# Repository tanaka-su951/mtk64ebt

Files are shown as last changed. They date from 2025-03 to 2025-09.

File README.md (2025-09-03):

## 目次

- [mtk64ebt](#mtk64ebt)
    - [トラックボール＆ロータリーエンコーダー付きBluetooth接続自作キーボード](#トラックボールロータリーエンコーダー付きbluetooth接続自作キーボード)
    - [フットスイッチ](#フットスイッチ)
- [オンラインストア](#オンラインストア)
- [本体以外に必要なパーツとおすすめ商品](#本体以外に必要なパーツとおすすめ商品)
- [特徴](#特徴)
- [使用方法](#使用方法)
    - [モジュール間接続](#モジュール間接続)
    - [USB接続](#usb接続)
    - [Bluetooth接続](#bluetooth接続)
    - [ロープロファイル化](#ロープロファイル化)
    - [フットスイッチ拡張キット](#フットスイッチ拡張キット)
    - [フットスイッチ無線化モジュール](#フットスイッチ無線化モジュール)
- [ファームウェア](#ファームウェア)
    - [左右構成用ファームウェア](#左右構成用ファームウェア)
    - [左右＋フットスイッチ無線化モジュール用ファームウェア](#左右フットスイッチ無線化モジュール用ファームウェア)
    - [ファームウェア書き込み](#ファームウェア書き込み)
- [ソースコード](#ソースコード)
    - [左右構成用ファームウェアブランチ](#左右構成用ファームウェアブランチ)
    - [左右＋フットスイッチ無線化モジュール用ブランチ](#左右フットスイッチ無線化モジュール用ブランチ)
- [ZMK Studioでキーマッピング変更](#zmk-studioでキーマッピング変更)
    - [ブラウザ版 ZMK Studio](#ブラウザ版-zmk-studio)
    - [アプリ版 ZMK Studio](#アプリ版-zmk-studio)
- [KeymapEditorでキーマッピング変更](#keymapeditorでキーマッピング変更)
- [トラックボール設定](#トラックボール設定)
    - [トラックボール設定変更](#トラックボール設定変更)
    - [レイヤー設定変更](#レイヤー設定変更)
    - [トラックボール設定値調整](#トラックボール設定値調整)
- [ケースデータ](#ケースデータ)

# mtk64ebt
<br>

### トラックボール＆ロータリーエンコーダー付きBluetooth接続自作キーボード

mtk64ebtは、親指操作トラックボールとロータリーエンコーダーを搭載した完全ワイヤレス接続分割式キーボードです。

トラックボールとエンコーダーの組み合わせにより、直感的で効率的な操作を実現します。

ワイヤレス接続によりケーブルの煩わしさから解放され、どこへでも快適に持ち運べます。

はんだ付けとケースの組み立てが完了している半完成キットです。キースイッチとキーキャップ、トラックボールを取り付けるだけで、すぐに使用を開始することができます。

#### Rev.3の特徴
基板設計とケース設計を更新してRev.3になりました。

##### バッテリーケースのスリム化
部品配置の見直しにより、バッテリーサイズはそのままでバッテリーケースをスリム化しました。(バッテリーケース部厚み 22mm → 18.5mm)
ケース形状も変更してすっきりした見た目になっています。

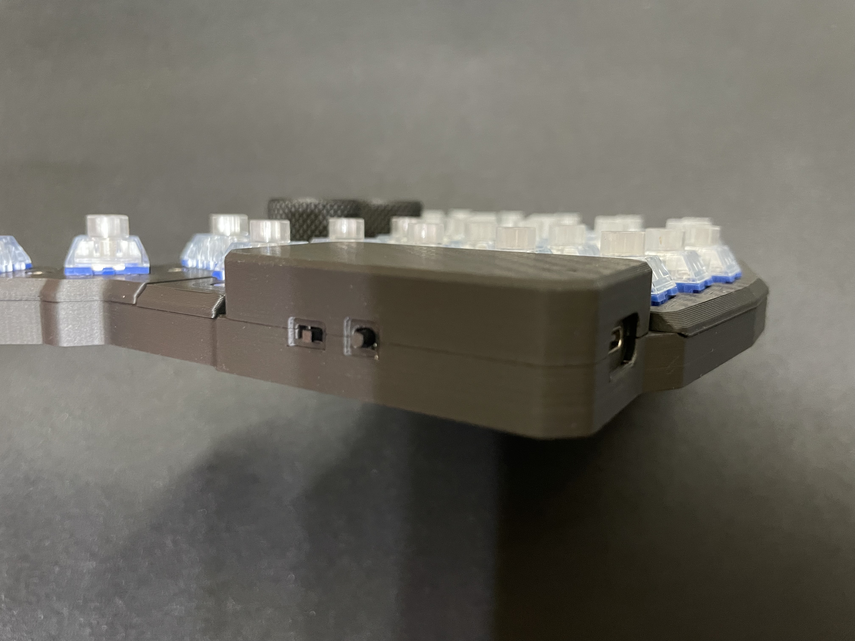
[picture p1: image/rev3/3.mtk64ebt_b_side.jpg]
<br>

##### LEDレンズ
インジケーターLEDにレンズを追加したことにより、視認性が向上しました。
バッテリー残量、接続状態、レイヤー切り替えが確認しやすくなりました。

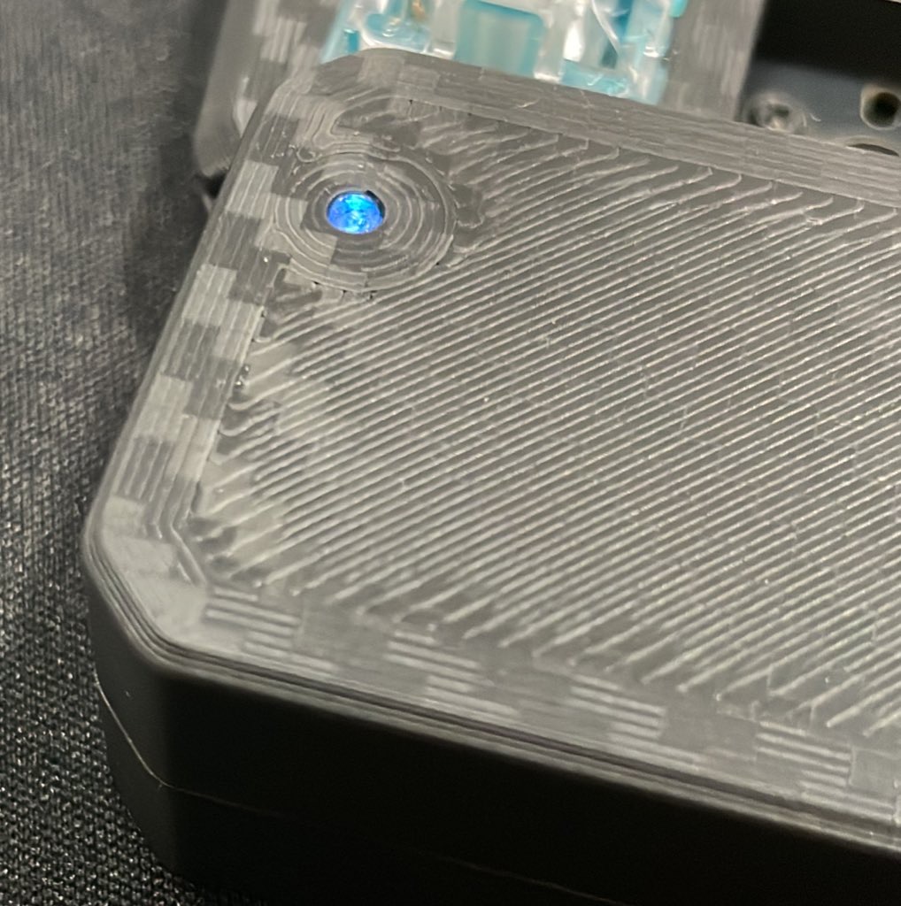
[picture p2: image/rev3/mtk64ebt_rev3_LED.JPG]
<br>

##### フットスイッチ完全無線化
ケーススリム化と生産性向上のため、左右キーボードのフットスイッチ有線接続ジャックを廃止。付属の無線フットスイッチキットによる無線接続に一本化しました。

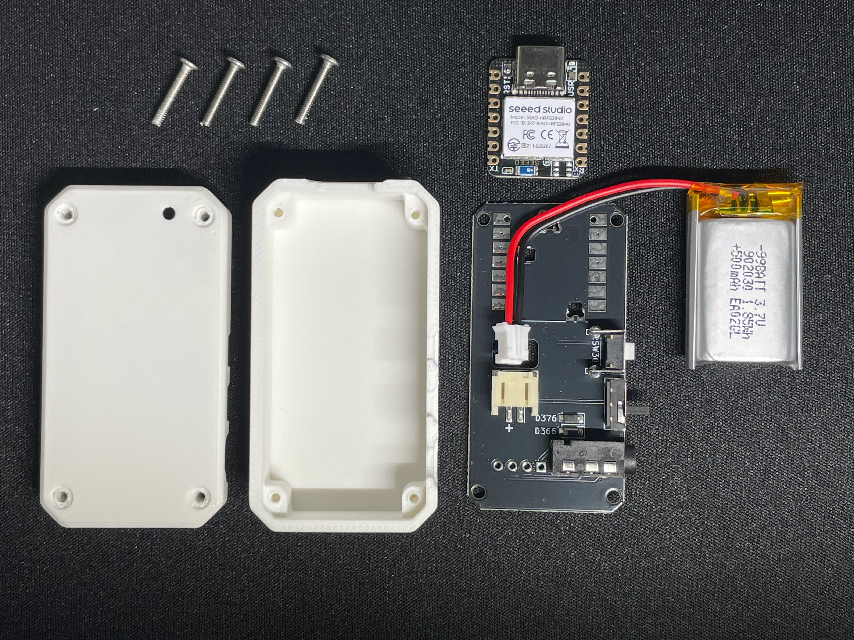
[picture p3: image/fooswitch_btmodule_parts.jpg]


##### ベアリング仕様トラックボールケース対応
トラックボール支持球をベアリングに置き換えるケースデータを公開しています。
ご自身でプリントしてベアリング仕様に変更可能です。

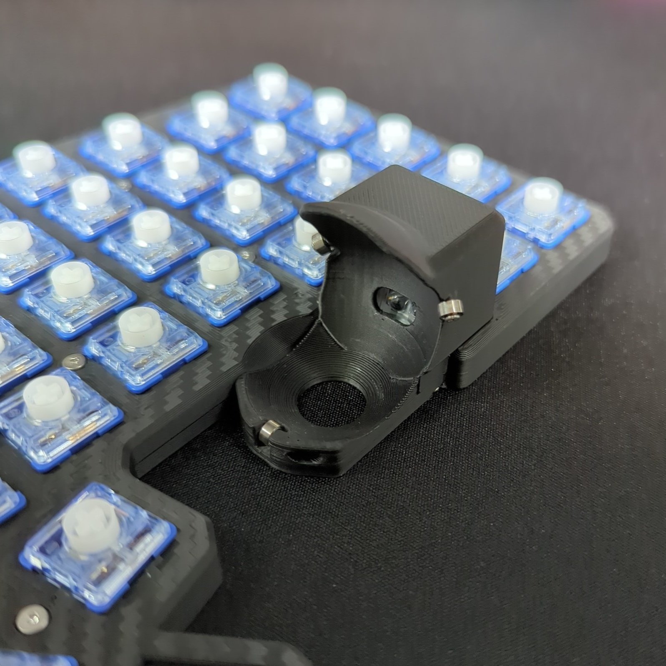
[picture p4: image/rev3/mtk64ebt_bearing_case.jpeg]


ケースの他に、ベアリング(内径 1.5mm 外径 4mm 幅 2mmのシールドタイプ)とM1.4のネジが必要です。
* ベアリング : [ミネベアミスミ DDL-415ZZ](https://amzn.asia/d/fXq8wOI)
* ネジ : [M1.4-0.3 6mm](https://amzn.asia/d/c3SDJWJ)

###### ベアリング仕様トラックボールケースデータ
[mtk64ebt_rev3_ballBearingCase_RH.3mf](casedata/rev3/mtk64ebt_rev3_ballBearingCase_RH.3mf)<br>[mtk64ebt_rev3_bodyBallBeringBottmn_RH.3mf](casedata/rev3/mtk64ebt_rev3_bodyBallBeringBottmn_RH.3mf)

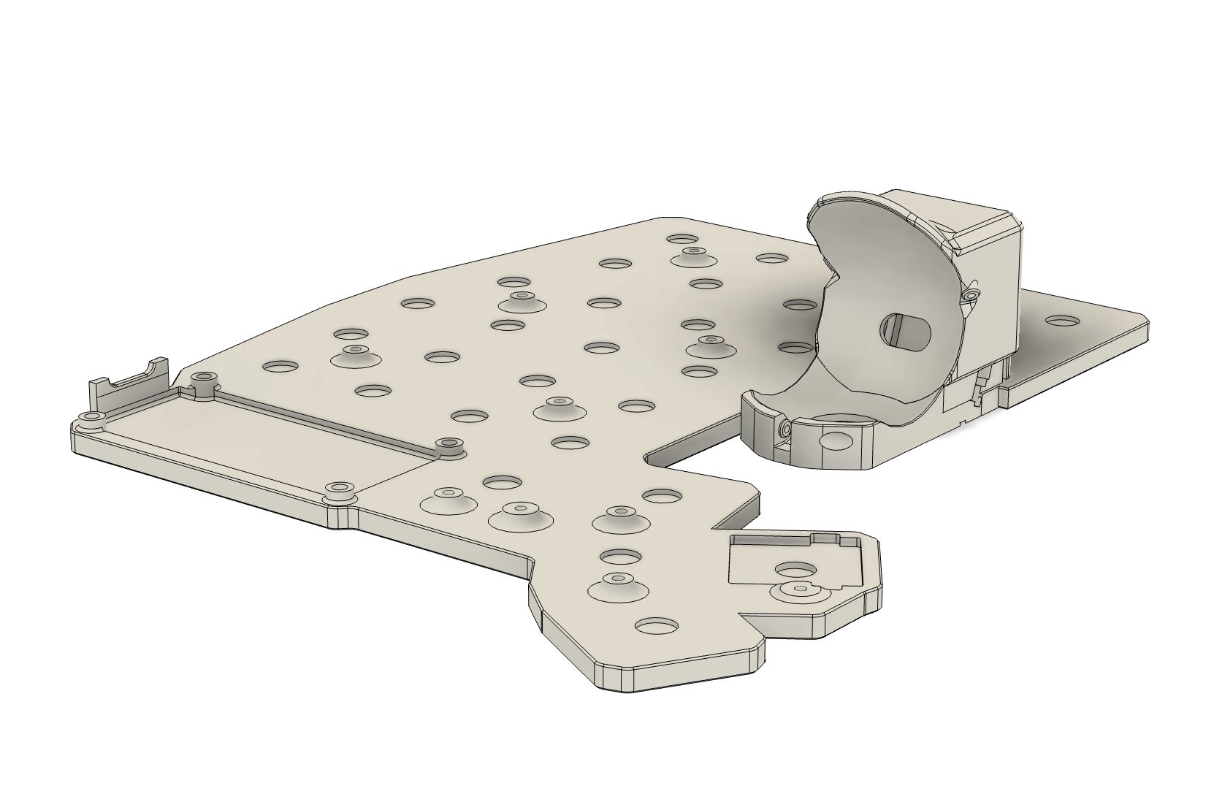
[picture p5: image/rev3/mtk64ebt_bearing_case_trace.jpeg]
<br>

### フットスイッチ
[市販のUSBフットスイッチ](https://amzn.asia/d/h7wMR24)の基板を付属のフットスイッチ拡張基盤に差し替えてmtk64の拡張無線フットスイッチとして使用可能です。

フットスイッチも含めて完全ワイヤレス化可能となり、デスク環境からケーブルの煩わしさを一掃できます。

フットスイッチ拡張基板はご自身ではんだ付けと組み立てが必要なキットです。

<br>

> [!CAUTION]
> バッテリー駆動用に[リチウムポリマーバッテリー](https://amzn.asia/d/1ivvf2l)を使用します。
> バッテリーの取り扱いを誤った場合や、製造上の不具合により、破裂や発火の恐れがあります。
> 組み立ての際に動作確認は行っていますが、絶対に安全であることを保証するものではありません。
> バッテリーは使用者の責任において使用してください。
> バッテリー、本体基板、その他構成部品を含め、本製品による事故および不利益損害についての一切の責任は使用者にあり、当方が責任を持つものではありません。

* バッテリー駆動時および、充電時は本体側面のバッテリー駆動用スイッチをONにしてください。
* バッテリー不使用時はバッテリー駆動用スイッチをOFFにしてください。
* 充電中は、発火・破裂しても被害のない場所を選定し、周囲に延焼するものを置かないようにして下さい。また充電中はその場を離れ ることなく常に Li-Po の充電状態を監視して下さい。
* バッテリーの取り扱いや製造上の不具合について懸念がある場合や、ご自身の責任で使用できない場合、キーボードからバッテリーを取り外してご使用ください。
USB端子からの給電のみでキーボードを使用できます。

## オンラインストア
https://mentako-ya.myshopify.com

## 本体以外に必要なパーツとおすすめ商品

キーキャップMX互換: [CORSAIR PBT DOUBLE-SHOT 交換用カラーキーキャップセット - 日本語108キー, Arctic White - CH-9911040-JP](https://amzn.asia/d/1FShFiO)

キーキャップChocV2: [XVX ロープロファイル PBT キーキャップ](https://amzn.asia/d/7V1A6T4)

キーキャップChocV1: [Chocfox CFX keycap](https://chosfox.com/products/chocfox-cfx-choc-keycaps?bg_ref=3KtshOemT6)

トラックボール: [ぺリックス PERIPRO-303WH 34mm](https://amzn.asia/d/1paUF5C)

USB Type-cケーブル: https://amzn.asia/d/h8pfZIJ

クッションゴム: [ダイソー クッションゴム透明](https://jp.daisonet.com/products/4903409153222)

T5ドライバー(メンテナンス用): [アネックス(ANEX) ドライバー ヘクスローブ T4x50](https://amzn.asia/d/8RFoACS)

## 特徴

標準的な６０％キーボード相当のキースイッチ＋フットスイッチ拡張で、一般的なキーボードからの移行コストを抑え、フルキーボード以上の操作性を実現します。

[ZMK Studio](#zmk-studioでキーマッピング変更)を使用して、キーマッピングを簡単に変更することができます。

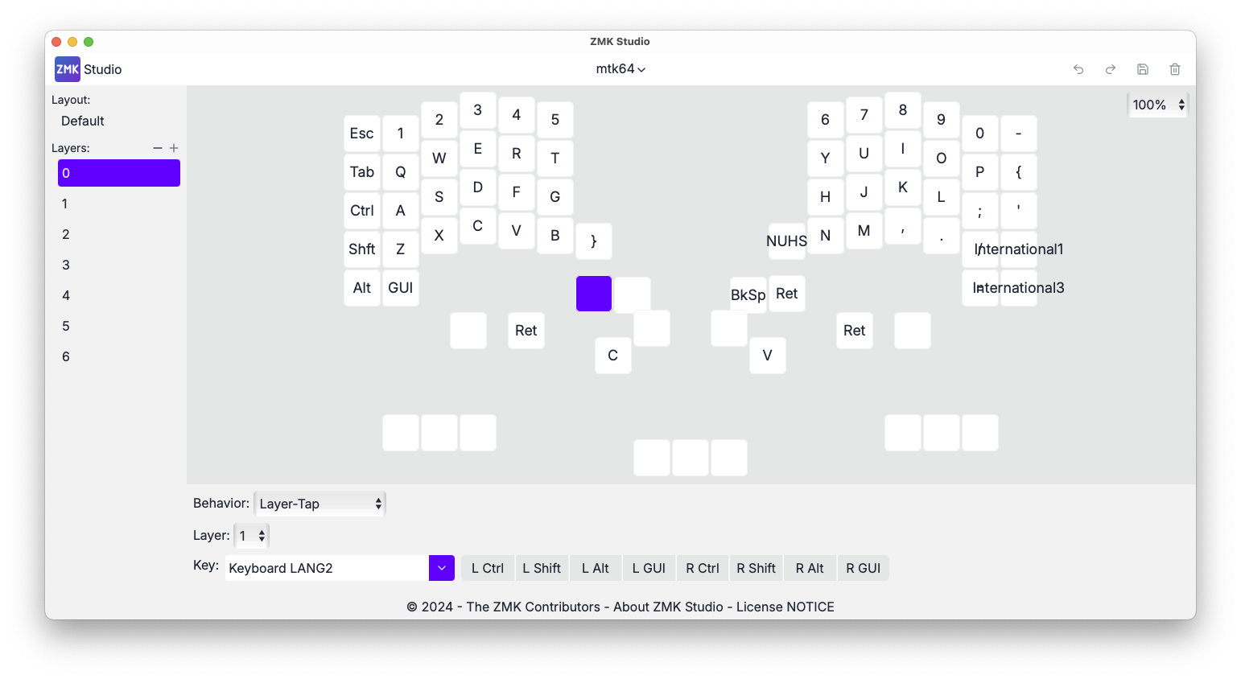
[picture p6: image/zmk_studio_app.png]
<br>

親指操作トラックボールを搭載しています。
キー操作時のトラックボールへの干渉を避けるため、トラックボールの取り付け位置は極力低くオフセットされています。
トラックボールケース底面もフラット形状にして、全体の高さを抑えました。

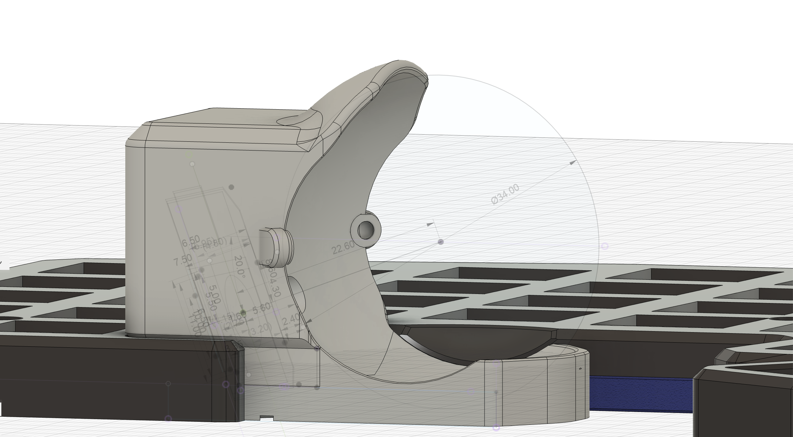
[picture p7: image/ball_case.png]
<br>

PMW3610トラックボールセンサーは、センサー基板を小型化して取り付け角度を20度に設定しました。
テンティングなしでも快適にトラックボールを操作することができます。

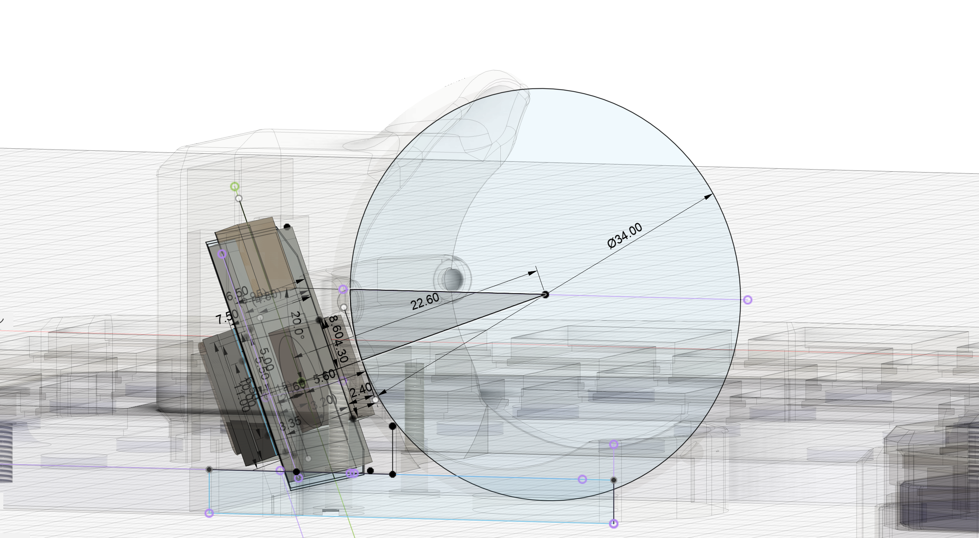
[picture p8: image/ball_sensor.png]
<br>

Alps alpine製の低背エンコーダーが２つ搭載されています。30クリックの回転操作とプッシュスイッチが付いており、直感的な操作が可能です。

<br>

Choc V1、[V2（固定ピンなしモデル）](https://ja.aliexpress.com/item/1005007361067887.html)、およびMX互換キースイッチを全てのキーに取り付けることが可能です。

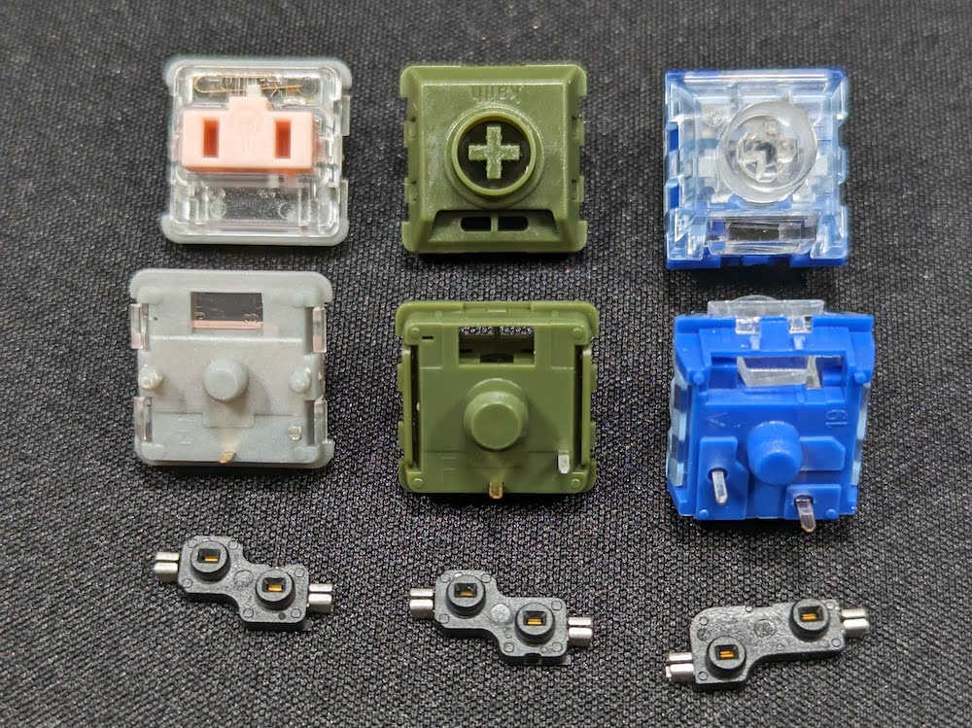
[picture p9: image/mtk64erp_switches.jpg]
<br>
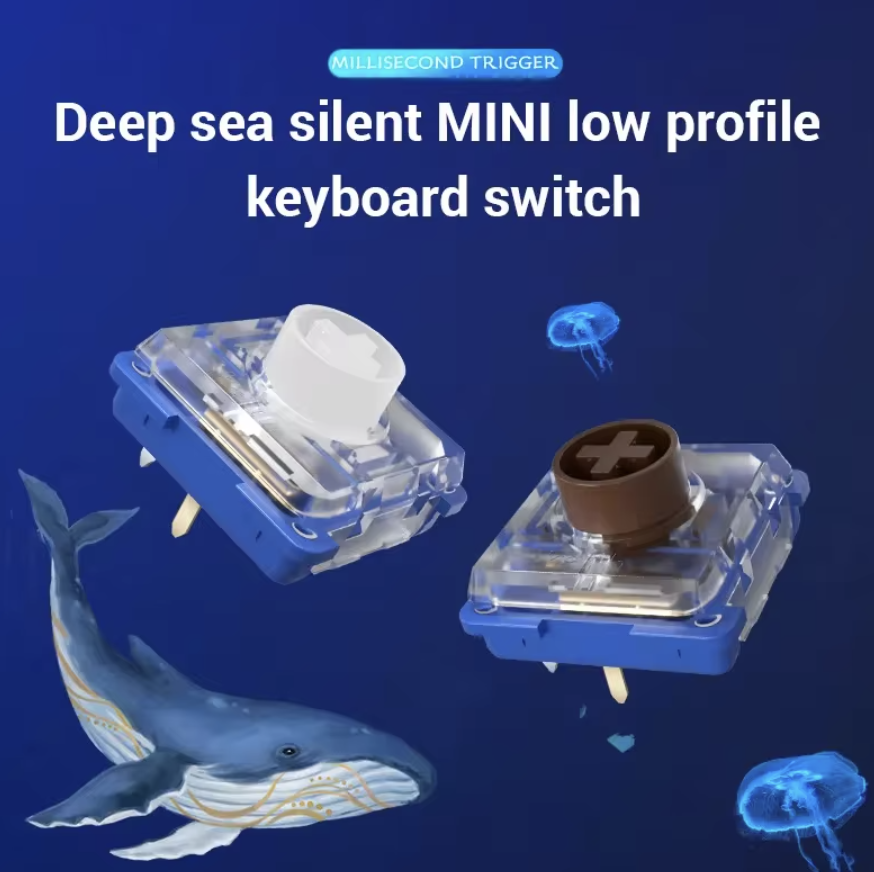
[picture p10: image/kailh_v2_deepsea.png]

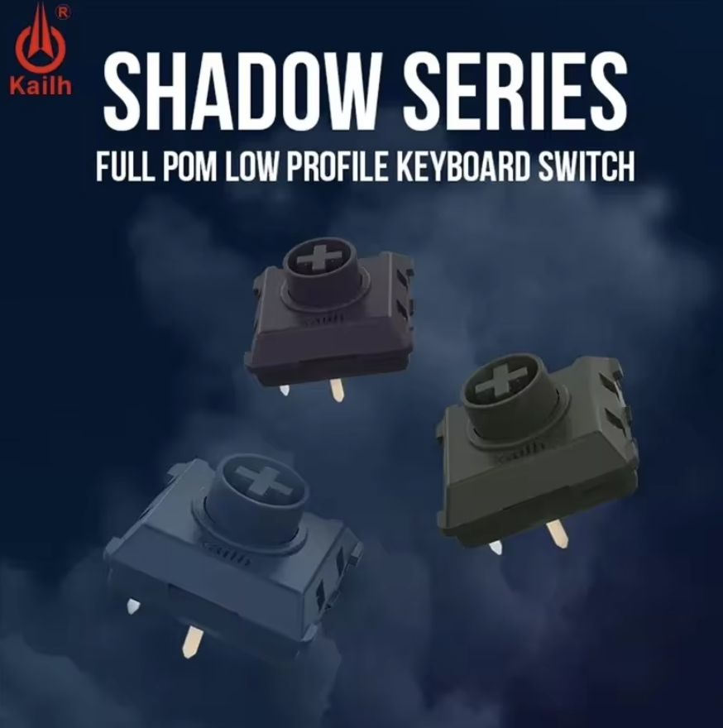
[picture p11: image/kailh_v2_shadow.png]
<br>

親指部分のみをロープロファイル化することも可能です。

追加の親指キースイッチは、操作性を向上させるため、さらに一段低くオフセットされています。

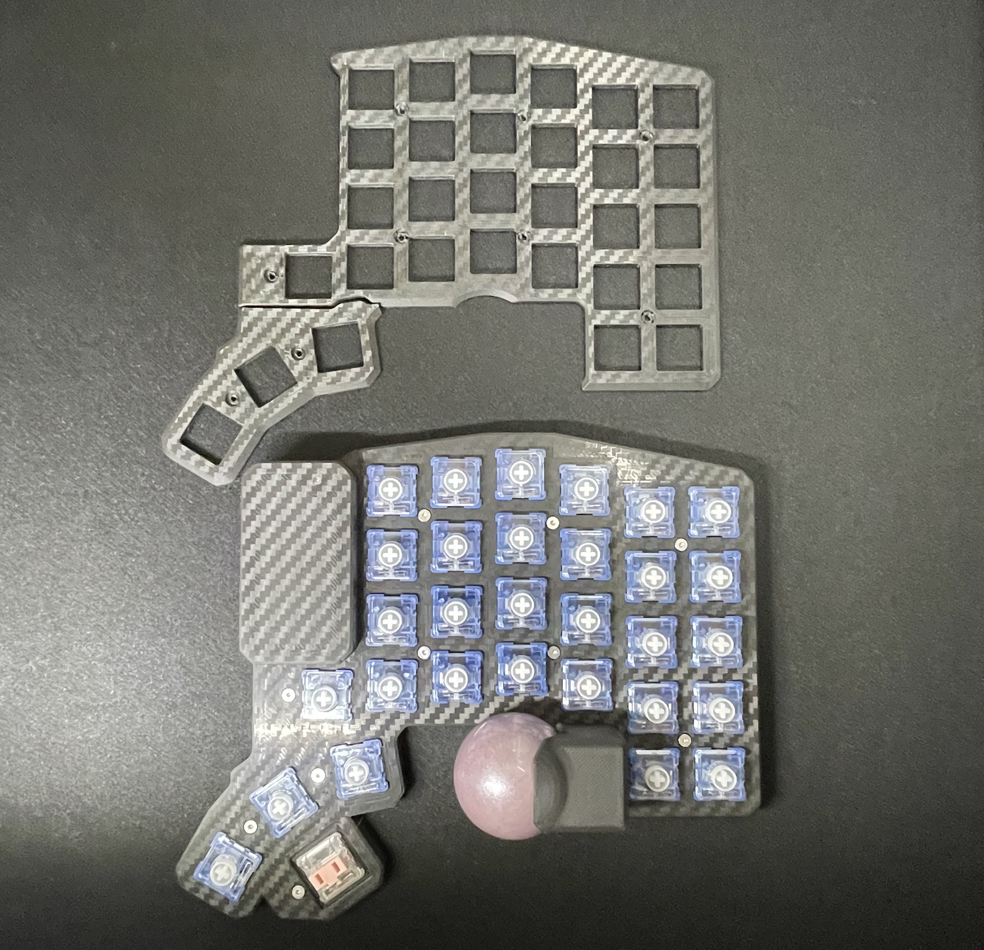
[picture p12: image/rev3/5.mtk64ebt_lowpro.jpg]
<br>

MCUに[Seeed Studio XIAO nRF52840](https://jp.seeedstudio.com/Seeed-XIAO-BLE-nRF52840-p-5201.html)を使用しており、無線接続の自作キーボードで課題となる技適対応もクリアしています。

技術基準適合証明番号：[211-220207](https://www.tele.soumu.go.jp/giteki/SearchServlet?pageID=jk01&NUM_TYPE=1&NUM=211-220207)

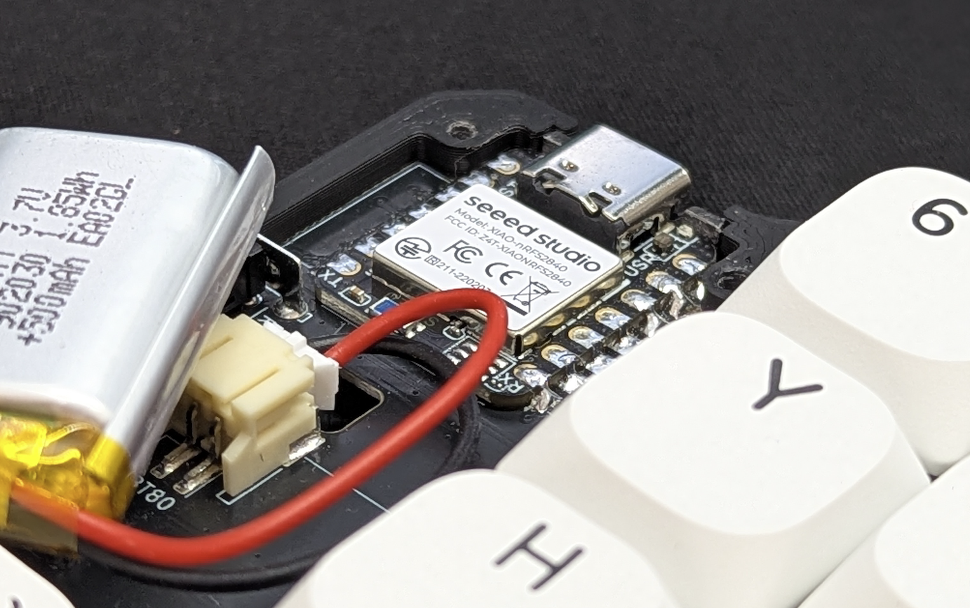
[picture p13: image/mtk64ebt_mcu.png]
<br>

無線接続では、有線接続に比べてポーリングレートが低くなりますが、通常利用には問題なく使用することが可能です。（約70hz）

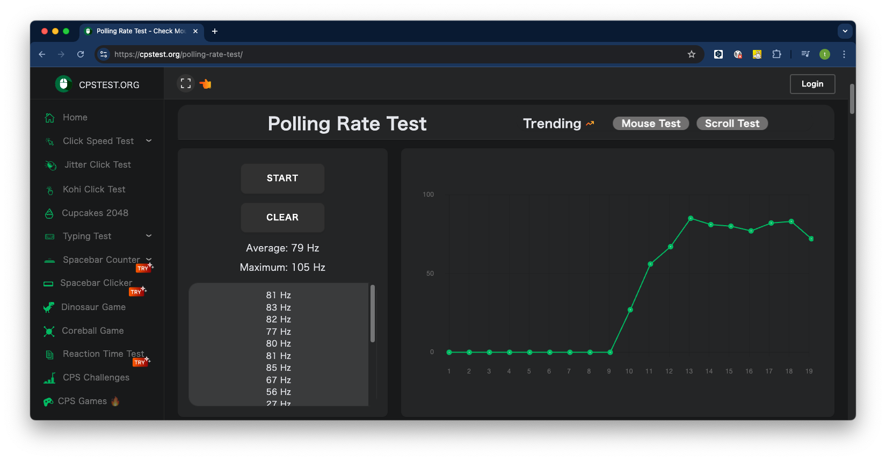
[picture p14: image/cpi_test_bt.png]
<br>

USB接続時には、ポーリングレートが向上し、よりスムーズに動作します。（約220hz）精密なトラックボール操作が求められる場面で効果的です。

有線接続時も右手のみUSB接続となり、左手側は無線接続となるので、USBケーブル１本だけで接続となります。左右間接続用のTRRSケーブルは使用しません。

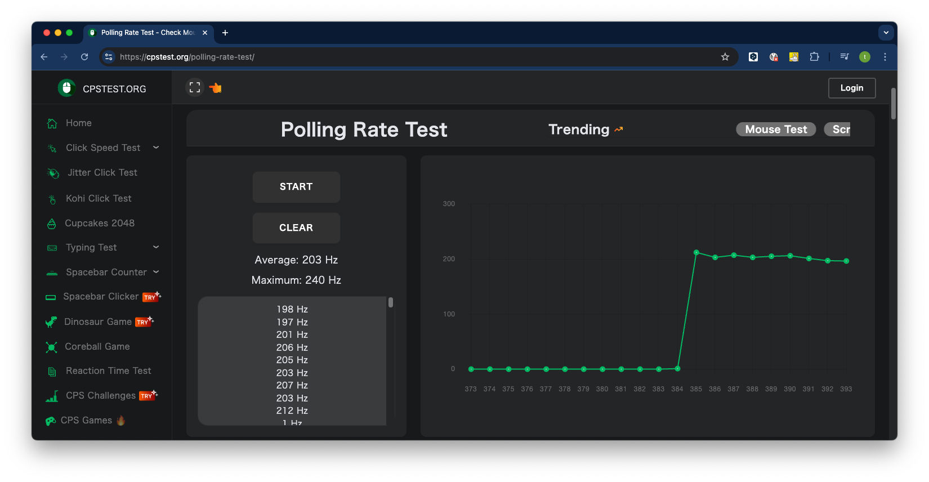
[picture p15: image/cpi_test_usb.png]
<br>

[Seeed Studio XIAO BLE](https://jp.seeedstudio.com/Seeed-XIAO-BLE-nRF52840-p-5201.html) もしくは [nrf54820搭載モジュール](https://www.switch-science.com/products/5531) をドングルとして使用することで、左右のキーボードは無線接続のまま、有線接続相当のポーリングレート（約110~220hz）で動作します。

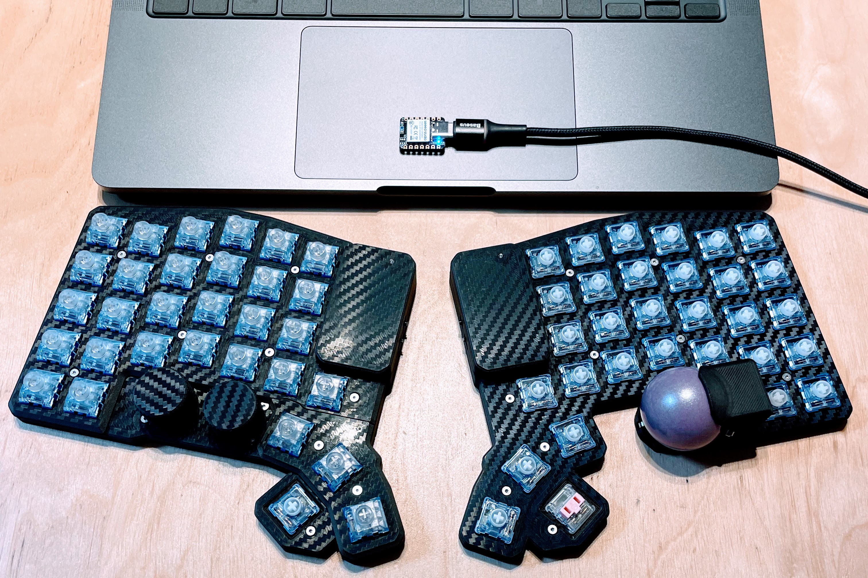
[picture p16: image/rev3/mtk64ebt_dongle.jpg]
<br>

[mtk64ebt ドングル使用時ポーリングレート計測ムービー](https://www.youtube.com/embed/7DrP1KA7Fw4?list=PL_GJMtxZ-TgovRiROU55VTm1dNuUvYyni)

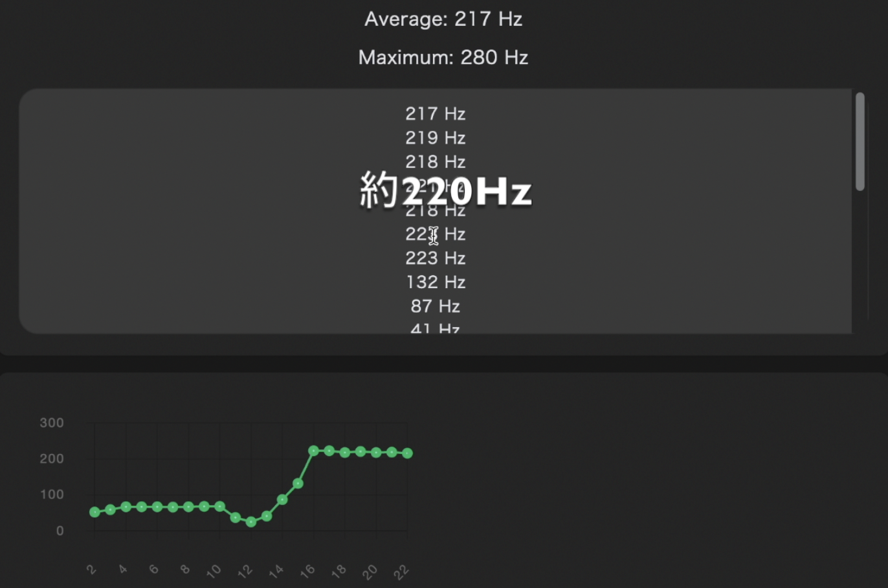
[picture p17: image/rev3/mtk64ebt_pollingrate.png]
<br>

右手側のLEDで現在のレイヤーが確認できるようになりました。
```
レイヤー０ ⚫️Black（無点灯）
レイヤー１ 🟣Magenta トラックボール精密モード
レイヤー２ 🔵Cyan    トラックボールモード
レイヤー３ 🟡Yellow  スクロールモード
レイヤー４ 🟢Green
レイヤー５ 🔵Blue
レイヤー６ ⚪️White   自動マウスレイヤー
```

## フットスイッチ拡張基板

[市販のUSBフットスイッチ](https://amzn.asia/d/h7wMR24)の基板を付属のフットスイッチ拡張基盤に差し替えてmtk64のフットスイッチとして使用可能です。

フットスイッチはmtk64の一部として機能するので、レイヤー切り替えやカスタムキーなどキーボード固有の操作が可能です。


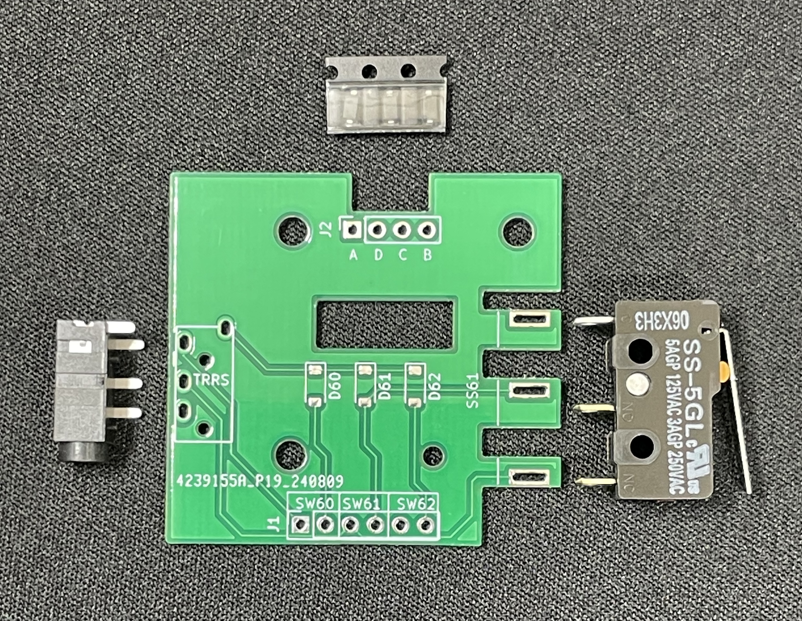
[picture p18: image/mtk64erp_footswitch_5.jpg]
<br>

フットスイッチ無線化モジュールに接続して、無線フットスイッチ構成にアップグレード可能です。

<br>  

# 使用方法

## モジュール間接続

mtk64bleは、右手モジュールがセントラルモジュールとして動作します。左手モジュールとフットスイッチは右手モジュールに自動的にペアリングされます。

各モジュールのLEDの色と接続状態については、[こちら](https://github.com/mentako-ya/zmk-rgbled-widget/blob/main/README.md)を参照してください。LEDの色によって接続状態が視覚的に確認できるため、接続状況を簡単に把握することができます。

各モジュール間の接続ができない場合は、ファームウェア書き込み手順に従って、各モジュールの接続をリセットしてください。接続の問題を解決して再度正常に動作させることができます。

## USB接続

右手モジュール（セントラルモジュール）は、PCとUSBで有線接続可能です。USB接続時、セントラルモジュールはPCとの通信を行いながら、充電も行います。

左手モジュールやフットスイッチ無線化モジュール（ペリフェラルモジュール）は、USB接続時に充電のみを行います。これらのモジュールは、操作に必要な通信をすべて無線接続でセントラルモジュールと行います。

> [!CAUTION]
> Rev.2以前の右手モジュールと左手モジュールにある3.5mmジャックはフットスイッチ拡張キットを有線接続するための端子です。
> 左右間の有線接続用ではありません。
> 故障の原因となるので、左右のキーボードをTRSケーブルで接続しないでください。

## Bluetooth接続

レイヤー1の「ESC」「1」〜「5」キーを使用して、最大６か所のBluetooth接続先を切り替えることができます。。



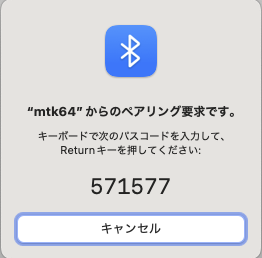
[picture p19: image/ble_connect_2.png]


接続時には、表示されたPIN番号を入力し、Enterキーを押下してください。接続後にキーボードが動作しない場合は、リセットボタンを押下して再接続を試みてください。これにより、接続の問題を解決し、正常に動作させることができます。

## ロープロファイル化

Choc V1、V2を使用する場合、トッププレート固定用ネジ(T5 8mm)を外してトッププレートを取り除き、付属の6mmねじに付け替えます。ネジの交換にはT5ドライバーを使用します。

## フットスイッチ拡張キット

フットスイッチ拡張キットはご自身で市販のフットスイッチにキットの基盤を組み込み、はんだ付けをするキットです。

フットスイッチの作成方法は[こちらのビルドムービー](https://youtu.be/NavGAliALVc?si=JpO-xi0RZznjVi4-)をご覧ください。

フットスイッチの接続は3.5mm４極のTRRS端子を使用しますが、有線でフットスイッチを接続する場合（3ccccqaac0cm以上のケーブル長が必要な場合）、市販のTRRSケーブルは線が細すぎるので使用できません

TRRS端子とAWG28~26以上（番号が小さい方が太いです）のケーブルを組み合わせて自作します

[遊舎工房自作ケーブルキット](https://shop.yushakobo.jp/products/self-made-cable?_pos=1&_sid=79305908f&_ss=r&variant=39623339737249)

[AWG26 4Cシールドケーブル](https://shop.oyaide.com/products/mogami_2893.html)

配線の色は使用するケーブルのメーカーによって異なります。
４極プラグの端子側とフットスイッチ拡張キット側の結線は下図を参照してください。

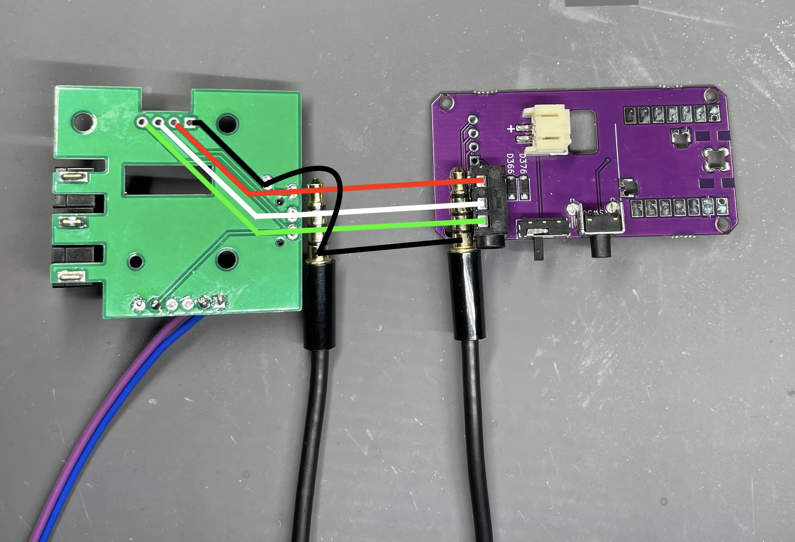
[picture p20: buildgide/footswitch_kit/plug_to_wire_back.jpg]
<br>
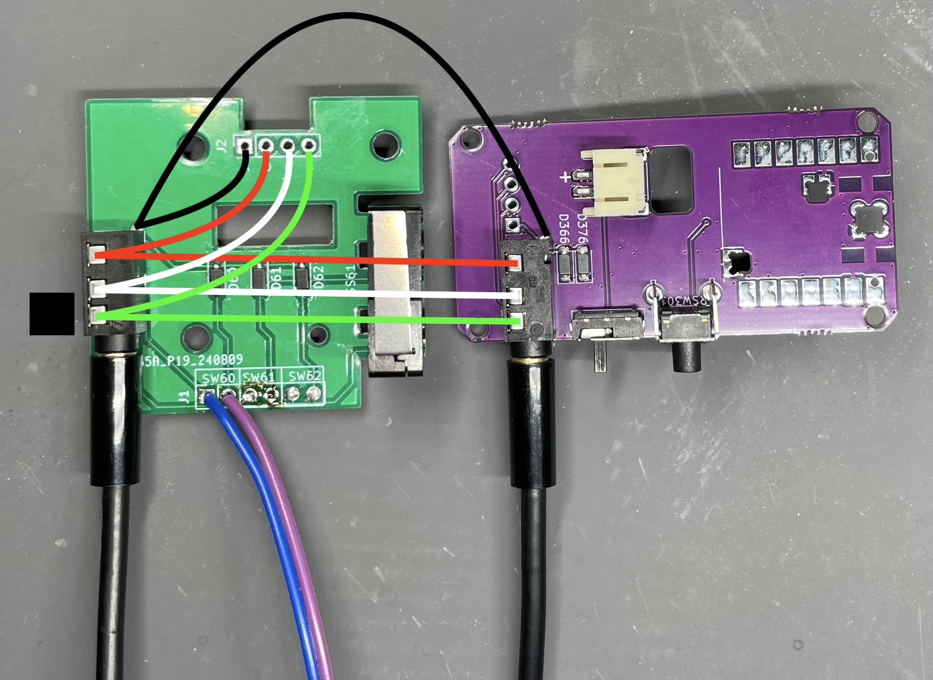
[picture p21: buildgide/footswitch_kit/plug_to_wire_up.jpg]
<br>
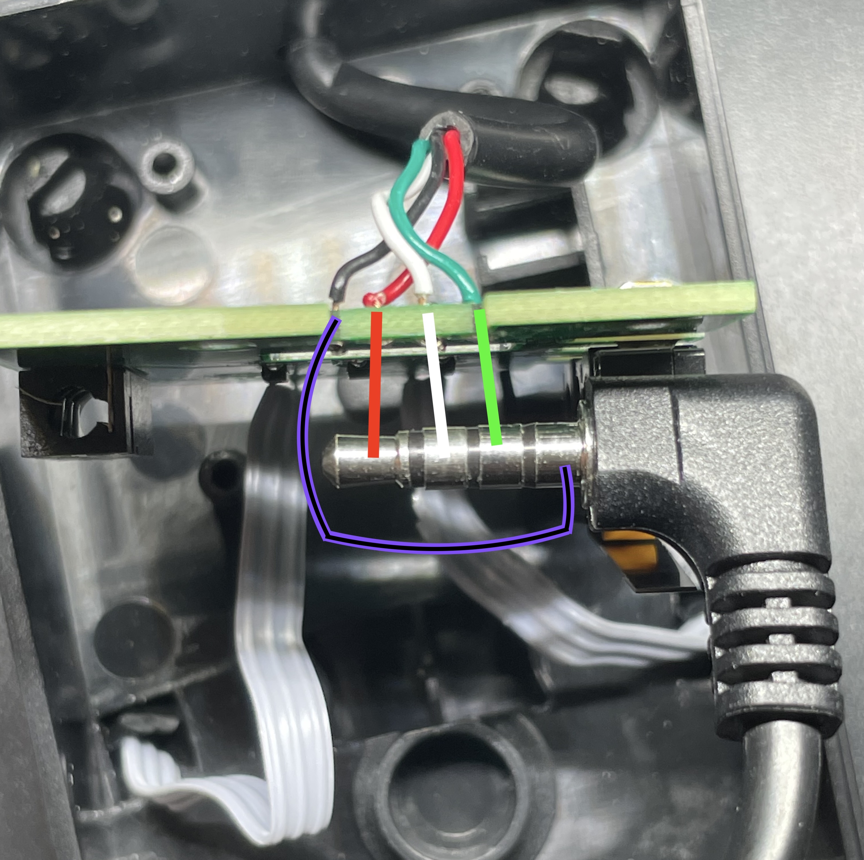
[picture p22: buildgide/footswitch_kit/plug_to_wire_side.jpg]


## フットスイッチ無線化モジュール

フットスイッチ無線化モジュールを使用する場合、[Seeed Studio XIAO nRF52840](https://jp.seeedstudio.com/Seeed-XIAO-BLE-nRF52840-p-5201.html)、[リチウムポリマーバッテリー 902030 PH2.0プラグ付き](https://ja.aliexpress.com/item/1005006838195720.html)、[ケース（ご自身で３Dプリント）](casedata/mtk64ebt_footmodule_case_LH.3mf) が別途必要です。

フットスイッチ拡張キットをフットスイッチ無線化モジュールに接続して、mtk64ebtに無線接続します。

フットスイッチキットとフットスイッチ無線化モジュールを接続する場合、フットスイッチ側の線を極力短くするのがオススメです。

写真は[こちらの４極3.5mm端子付きケーブル](https://www.digikey.jp/ja/products/detail/assmann-wsw-components/A-AV-02-45-28-183-S2/16906692)を15cmにカットして使用しています。


 

## ファームウェア

### 左右構成用ファームウェア
[mtk64ebt_Right_Left.zip](firmware/mtk64ebt_Right_Left.zip)

> [!IMPORTANT]
> フットスイッチ無線化モジュールを使用しない場合、こちらのファームウェアを使用してください。
> フットスイッチ無線化モジュールとの通信待ちで動作が遅くなる場合があります。

### 左右＋フットスイッチ無線化モジュール用ファームウェア
[mtk64ebt_Right_Left_Foot.zip](firmware/mtk64ebt_Right_Left_Foot.zip)

### 左右＋ドングルモジュール用ファームウェア
[mtk64ebt_Right_Left_Dongle.zip](firmware/mtk64ebt_Right_Left_Dongle.zip)

[Seeed Studio XIAO BLE](https://jp.seeedstudio.com/Seeed-XIAO-BLE-nRF52840-p-5201.html) もしくは [nrf54820搭載モジュール](https://www.switch-science.com/products/5531) をドングルとして使用するファームウェアです

### ファームウェア書き込み

1. 右手キーボード、左手手キーボード、フットスイッチ拡張モジュールのバッテリー駆動スイッチをOFFにする

> [!IMPORTANT]
> バッテリーから給電された状態ではファームウェア書き込み後のリセットが正しく行われません

1. 右手キーボードをPCにUSB接続してリセットボタンを短く2回押下

1. 認識された”XIAO-SENSE"に settings_reset-seeeduino_xiao_ble-zmk.uf2 をドロップ

1. 再度リセットボタンを短く2回押下

1. 認識された”XIAO-SENSE"に mtk64_R rgbled_adapter-seeeduino_xiao_ble-zmk.uf2 をドロップ

1. 左手キーボードをPCにUSB接続してリセットボタンを短く2回押下

1. 認識された”XIAO-SENSE"にsettings_reset-seeeduino_xiao_ble-zmk.uf2をドロップ

1. 再度リセットボタンを短く2回押下

1. 認識された”XIAO-SENSE"に mtk64_L rgbled_adapter-seeeduino_xiao_ble-zmk.uf2 をドロップ

1. フットスイッチ無線化モジュールをPCにUSB接続してリセットボタンを短く2回押下

1. 認識された”XIAO-SENSE"にsettings_reset-seeeduino_xiao_ble-zmk.uf2をドロップ

1. 再度リセットボタンを短く2回押下

1. 認識された”XIAO-SENSE"に mtk64_FOOT rgbled_adapter-seeeduino_xiao_ble-zmk.uf2 をドロップ

1. 右手キーボードをPCにUSB接続、左手キーボードとフットスイッチ拡張モジュールはバッテリー駆動スイッチをONにして給電する

1. 各モジュールのリセットスイッチを１回押下、各モジュール間の接続状態をUSB端子横のLEDで確認

- 右手のLEDはPCとのBluetooth接続状態を表す。
接続中🔵、オープン (アドバタイズ)🟡、切断中🔴 が点滅

- 左手とフットスイッチ無線化モジュールのLEDは、右手（セントラル）とのペアリング状態を表す。
接続の場合は🔵、切断の場合は🔴が点滅

LEDの色と接続状態についての詳細は[こちら](https://github.com/mentako-ya/zmk-rgbled-widget/blob/main/README.md)

## ソースコード

https://github.com/mentako-ya/zmk-config-mtk64

#### 左右構成用ファームウェアブランチ

https://github.com/mentako-ya/zmk-config-mtk64/tree/nofoot

#### 左右＋フットスイッチ無線化モジュール用ブランチ

https://github.com/mentako-ya/zmk-config-mtk64/tree/master

#### 左右＋ドングルモジュール用ブランチ

https://github.com/mentako-ya/zmk-config-mtk64/tree/pmw3610-bj-dongle

## ZMK Studioでキーマッピング変更

ZMK Studioを使用することで、ファームウェア書き換えなしでキーマッピングを簡単に変更することができます。

<br>

### ブラウザ版 ZMK Studio
ブラウザ版のZMK Studioを使用する場合、右手側のモジュールをUSB接続し、[こちら](https://zmk.studio/)にアクセスしてください。

### アプリ版 ZMK Studio
アプリ版のZMK Studioは、[こちら](https://zmk.studio/download)からダウンロードできます。アプリ版では、無線接続のままキーマップの変更が可能です。ケーブルを接続する手間を省き、より柔軟にキーマッピングを調整することができます。

## KeymapEditorでキーマッピング変更

キースイッチのマッピングだけでなく、エンコーダーのキーマッピング、マクロやコンボの追加、編集をしたい場合、[キーマップエディター](https://nickcoutsos.github.io/keymap-editor/)を使用して変更可能です。

キーマップエディターでマッピングを変更するためには、ご自身のgithubアカウントでmtk64ebtのファームウェアリポジトリをフォークして、キーマップエディターで編集する必要があります。

操作はブラウザだけで完結するので、特別なツールは不要です。

1. https://github.com/mentako-ya/zmk-config-mtk64 を開いて画面右上の「Fork」をクリック

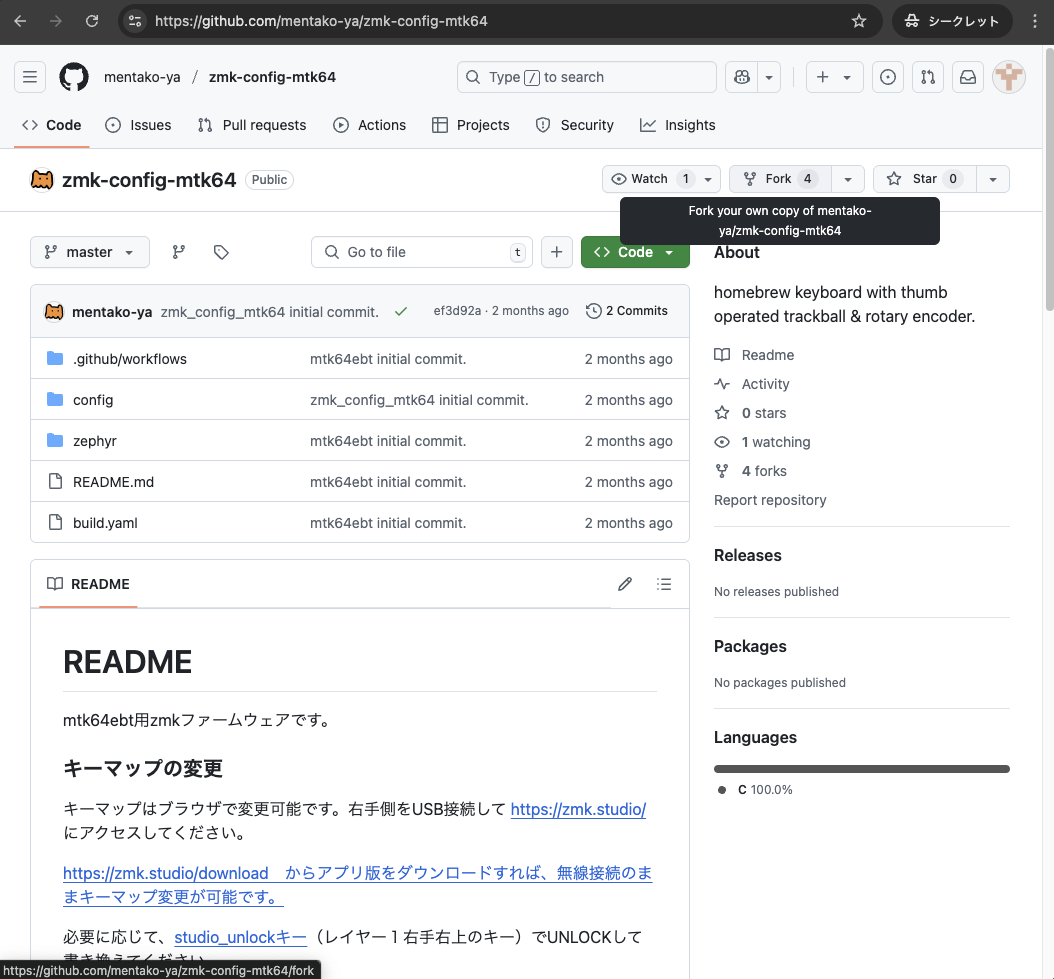
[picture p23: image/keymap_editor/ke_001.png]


2. 「Copy the master branch only」のチェックボックスを外してから、「Create fork」のボタンをクリック

> [!CAUTION]
> 「Copy the master branch only」のチェックボックスを外してください<br>
> チェックをつけたままフォークすると、master以外のブランチ（nofootなど）がコピーされません

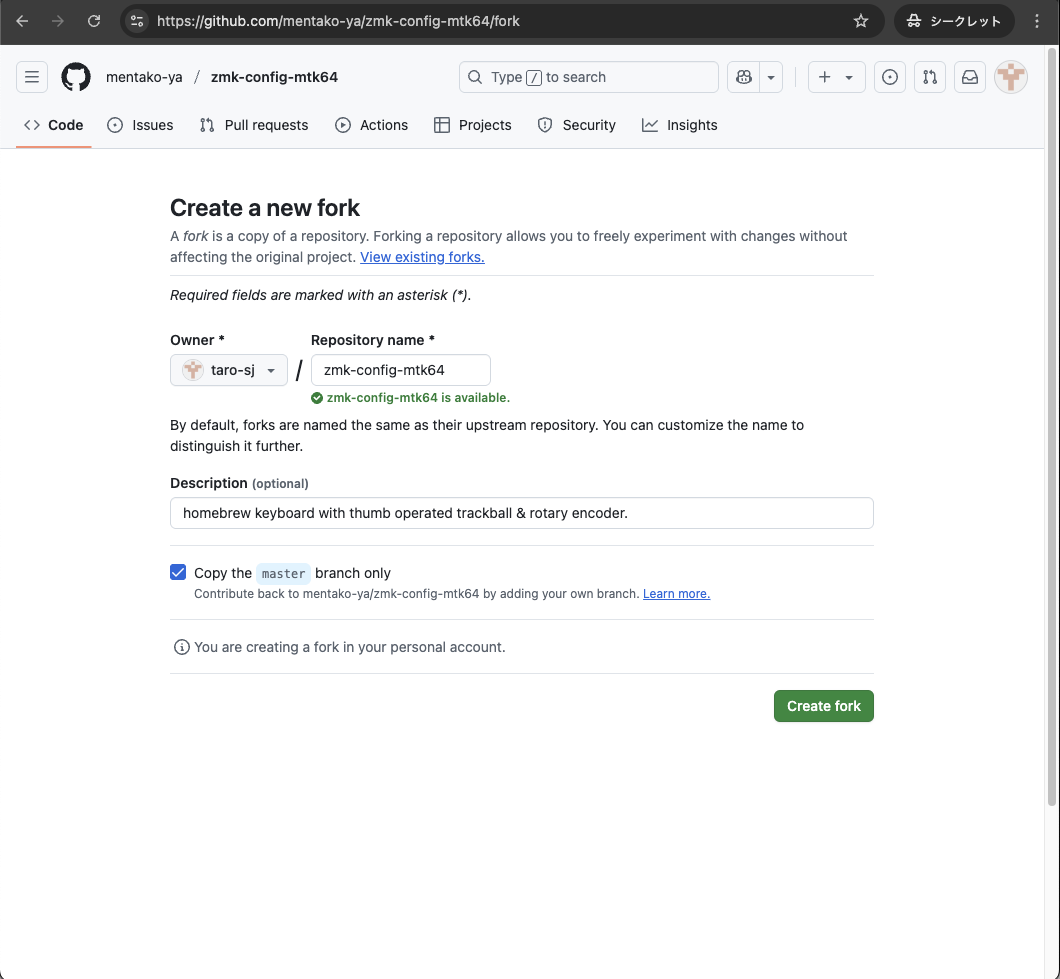
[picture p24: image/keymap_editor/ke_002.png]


3. ご自身のgitHubアカウントにzmk-config-mtk64のフォークが作成されます

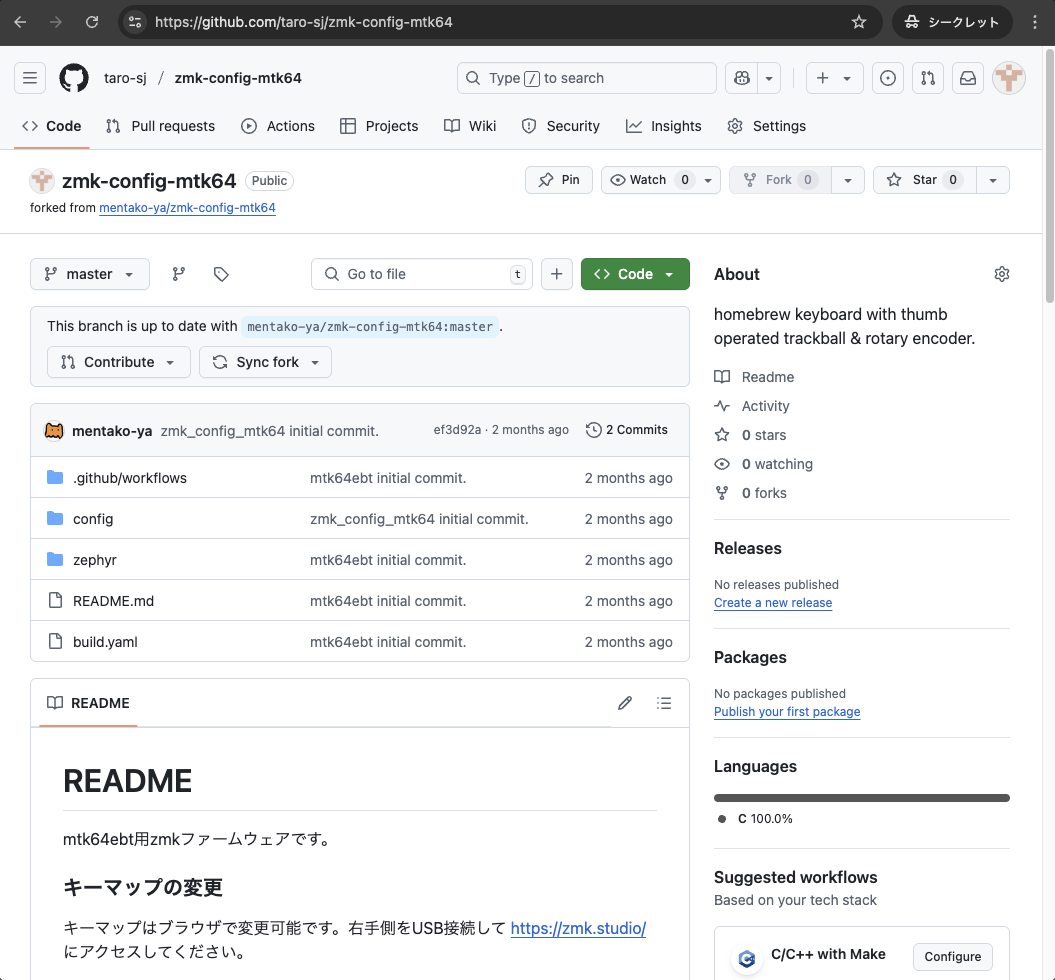
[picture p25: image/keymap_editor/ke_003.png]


4. https://nickcoutsos.github.io/keymap-editor/ を開いて「GitHUb」のアイコンをクリック

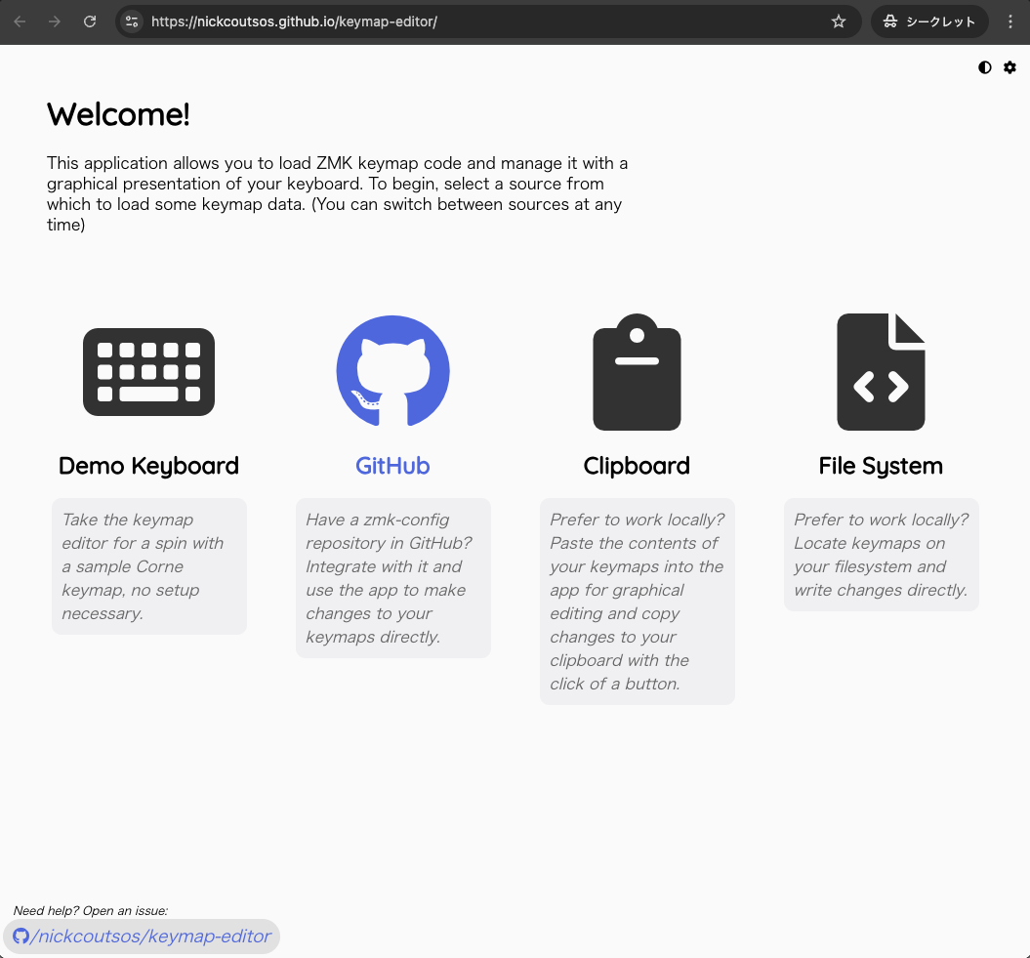
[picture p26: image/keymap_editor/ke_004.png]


5. 先ほどzmk-config-mtk64のフォークを作成したGitHubのアカウントで認証

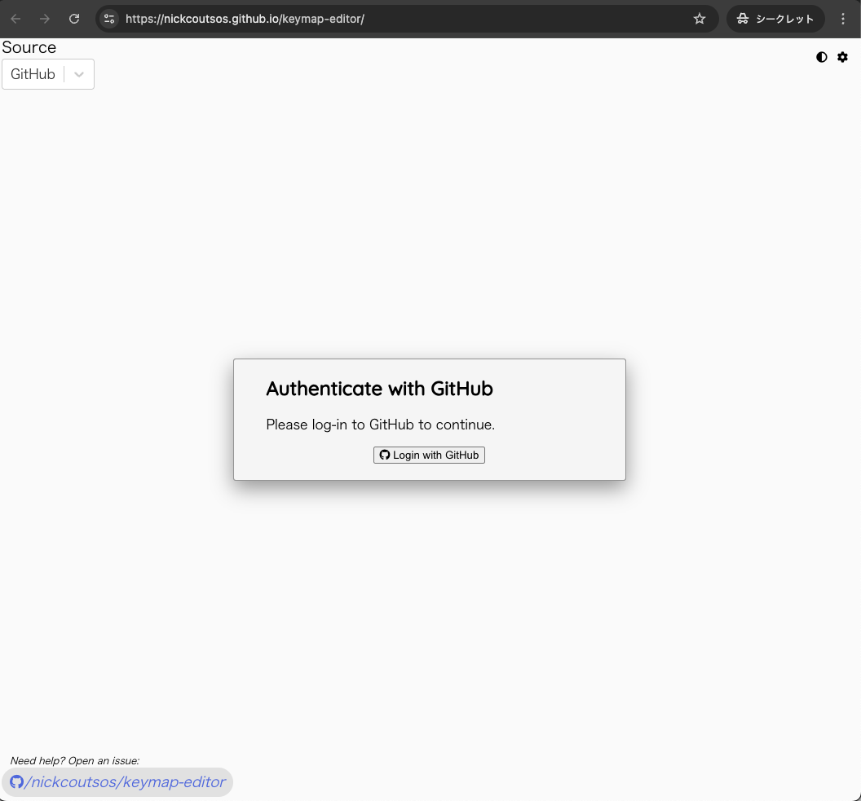
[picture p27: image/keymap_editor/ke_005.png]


6. 「Authorize Keymap Editor」をクリック

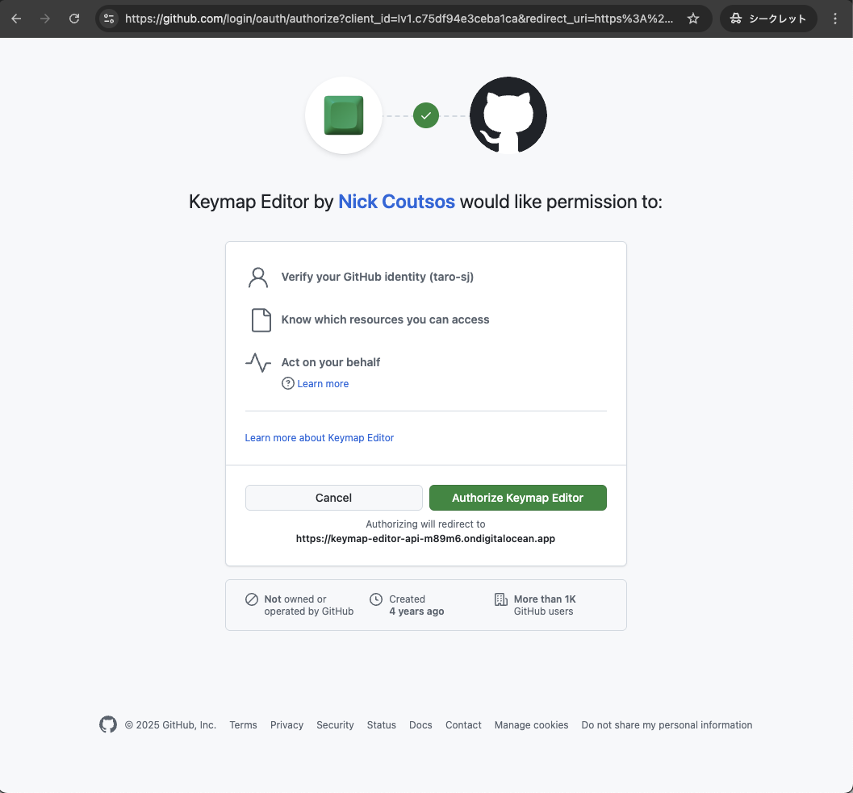
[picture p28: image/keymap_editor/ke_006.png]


7. 「Add Repository」をクリック

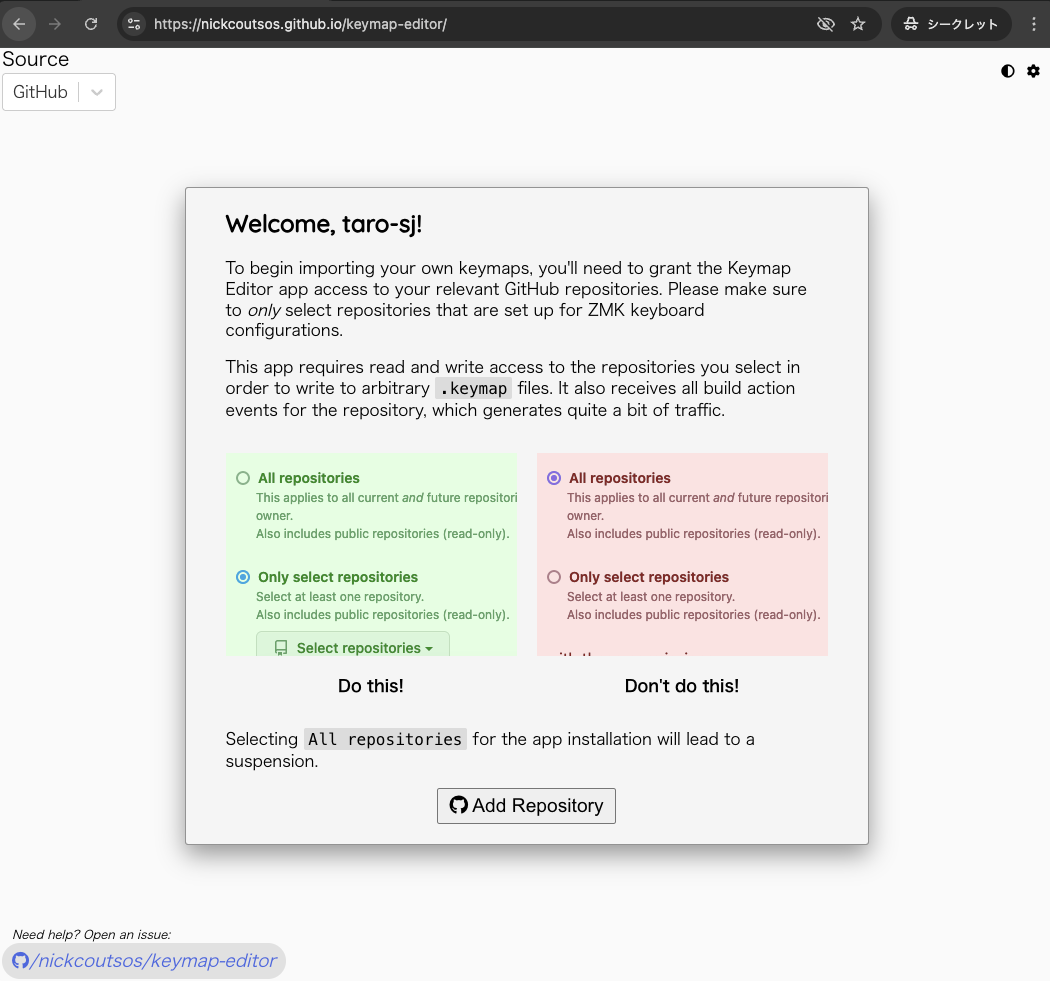
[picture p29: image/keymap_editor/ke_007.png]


8. 「Only select repositories」のラジオボタンを選択 -> 「Select repositories」のプルダウンから「zmk-config-mtk64」を選択 -> 「Install」をクリック

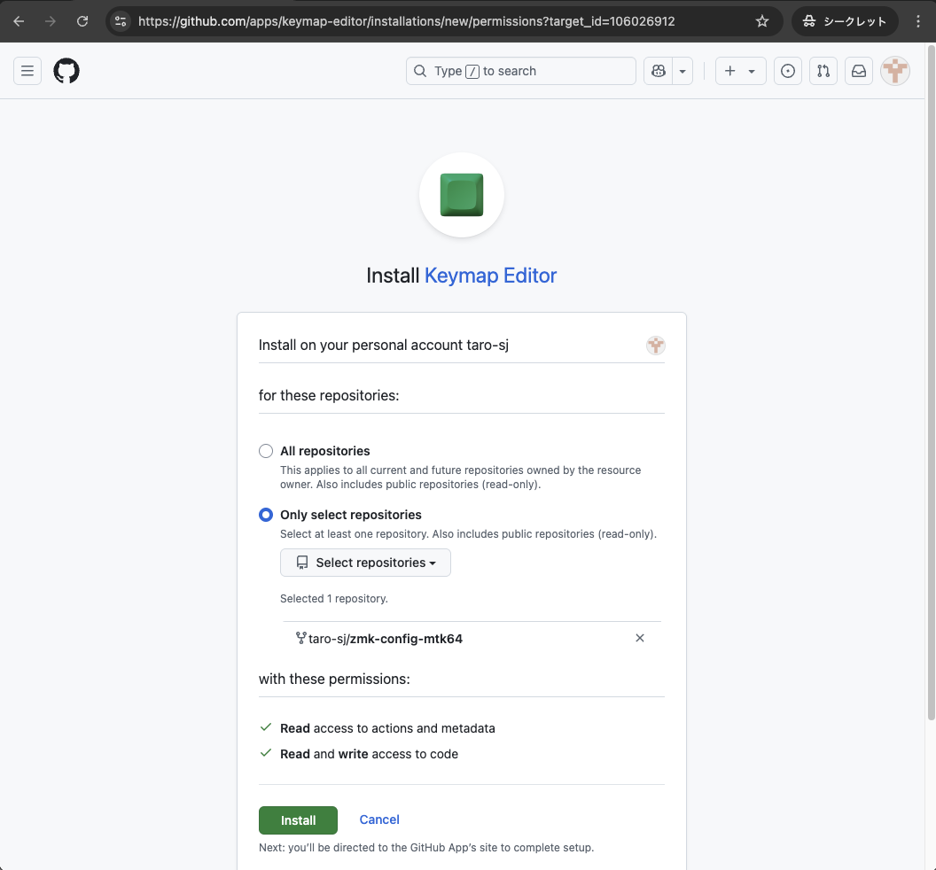
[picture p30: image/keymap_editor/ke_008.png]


9. キーマップエディター画面でフォークしたリポジトリとブランチを選択　フットスイッチ無線化モジュールを使用する場合masterブランチを選択　フットスイッチ無線化モジュールを使用しない場合nofootブランチを選択

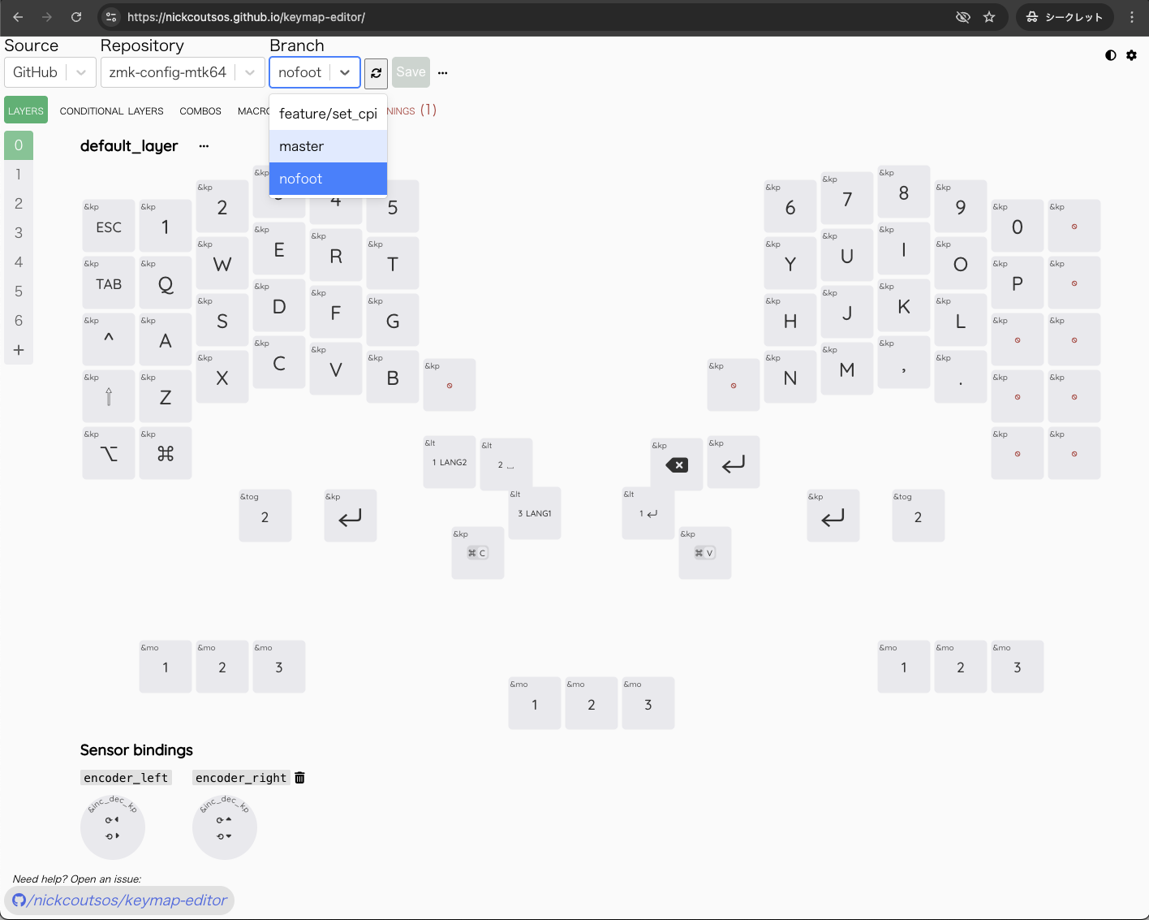
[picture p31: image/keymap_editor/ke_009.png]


10. キーをクリックして編集　例として、エンコーダーのキーマップを変更

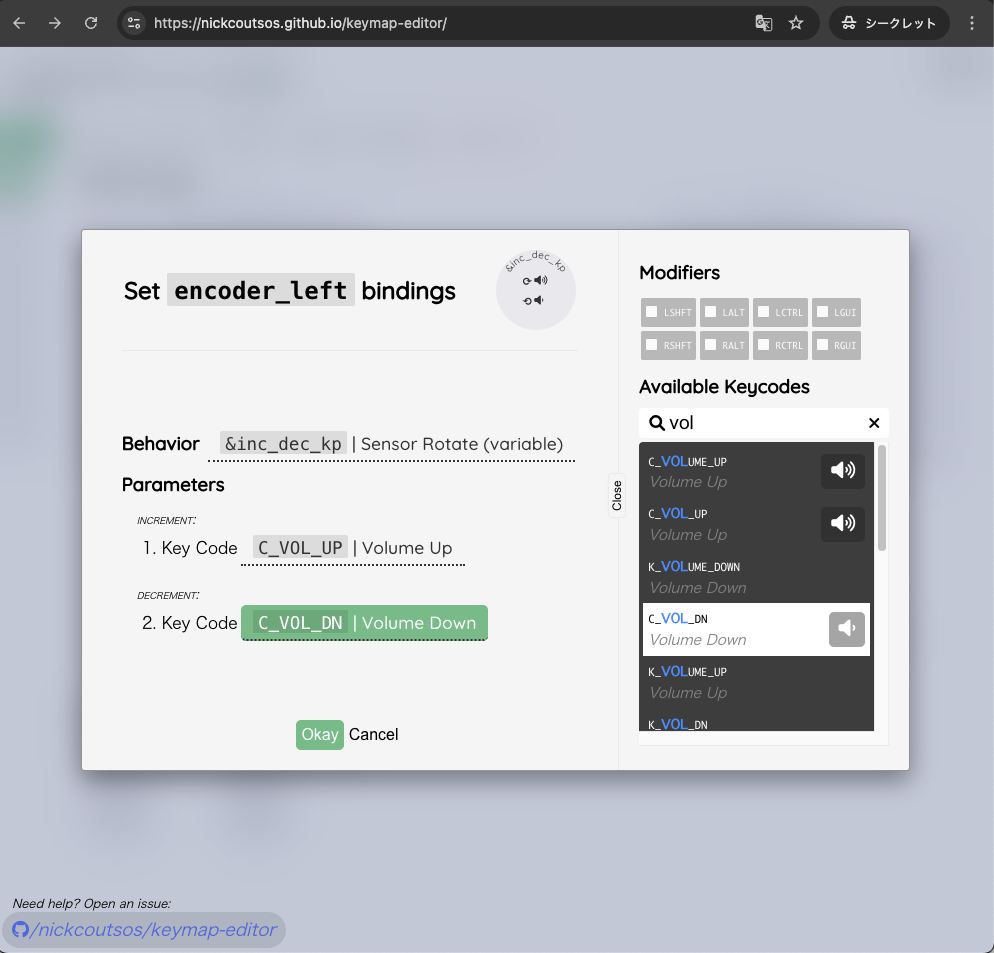
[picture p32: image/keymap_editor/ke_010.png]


11. saveボタンを押して変更したキーマップをコミット

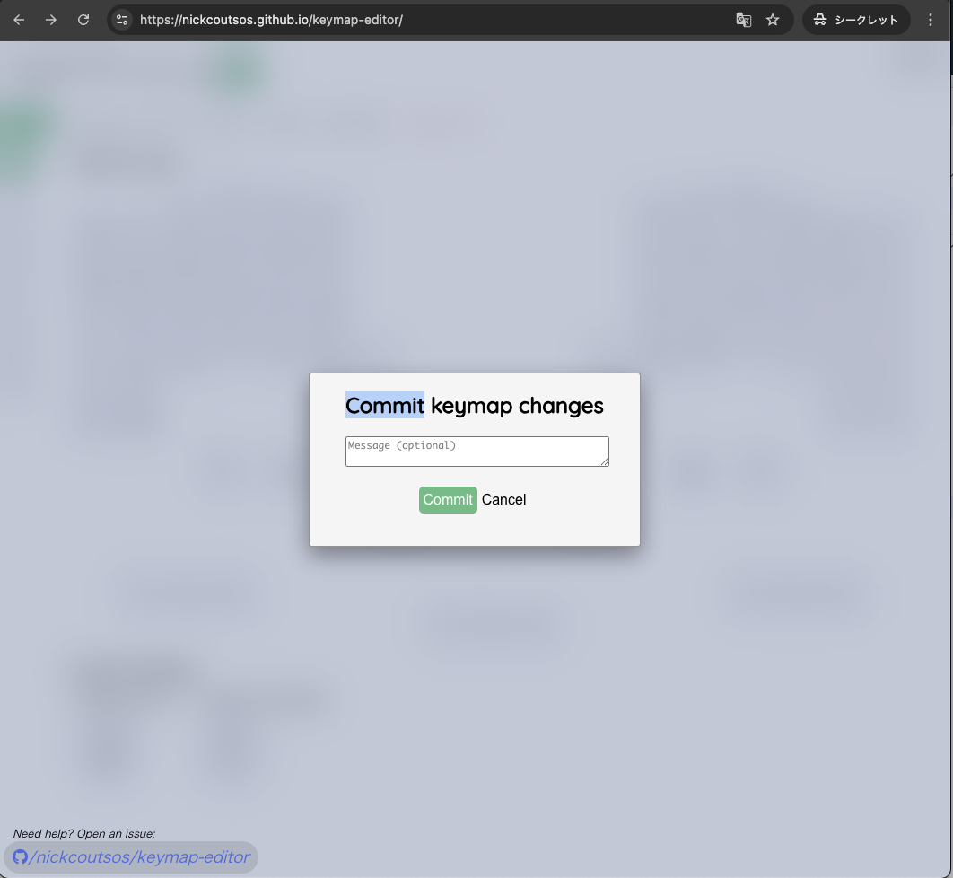
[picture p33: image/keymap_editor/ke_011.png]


12. フォークした自分のzmk-config-mtk64リポジトリをブラウザで開く -> Actionsメニュー　-> .github/workflows/build.yml選択 ->  「Run workflow」クリック-> Run workflow

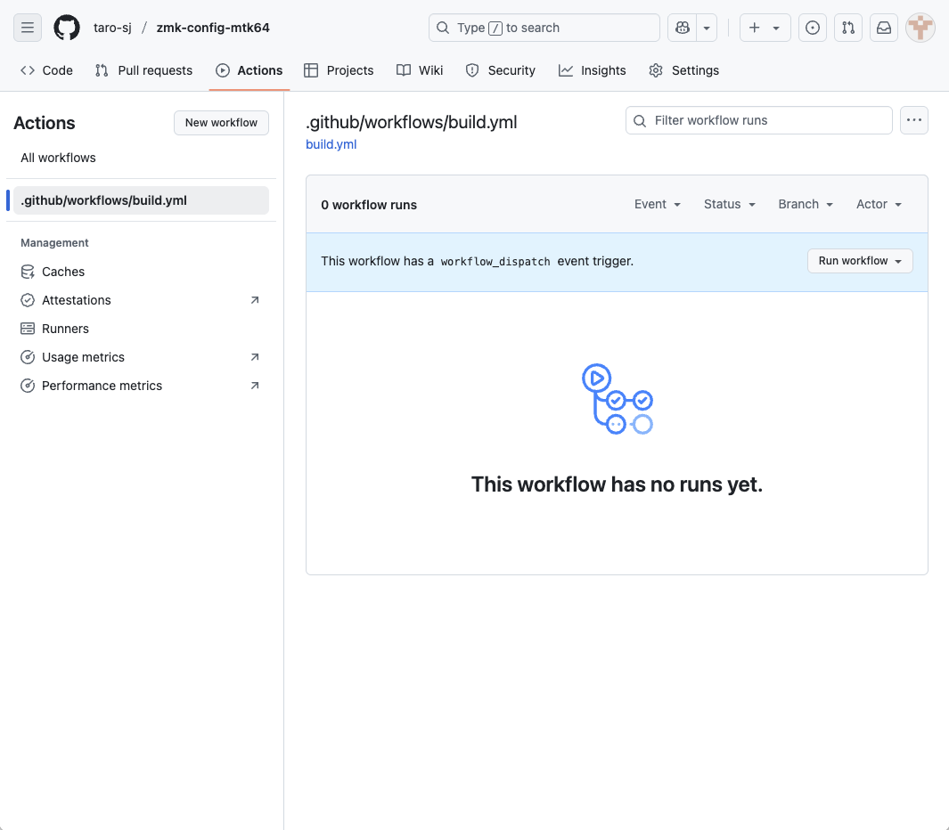
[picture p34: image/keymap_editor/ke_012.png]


13. 実行完了後、「Merge Output Artifacts」を開く

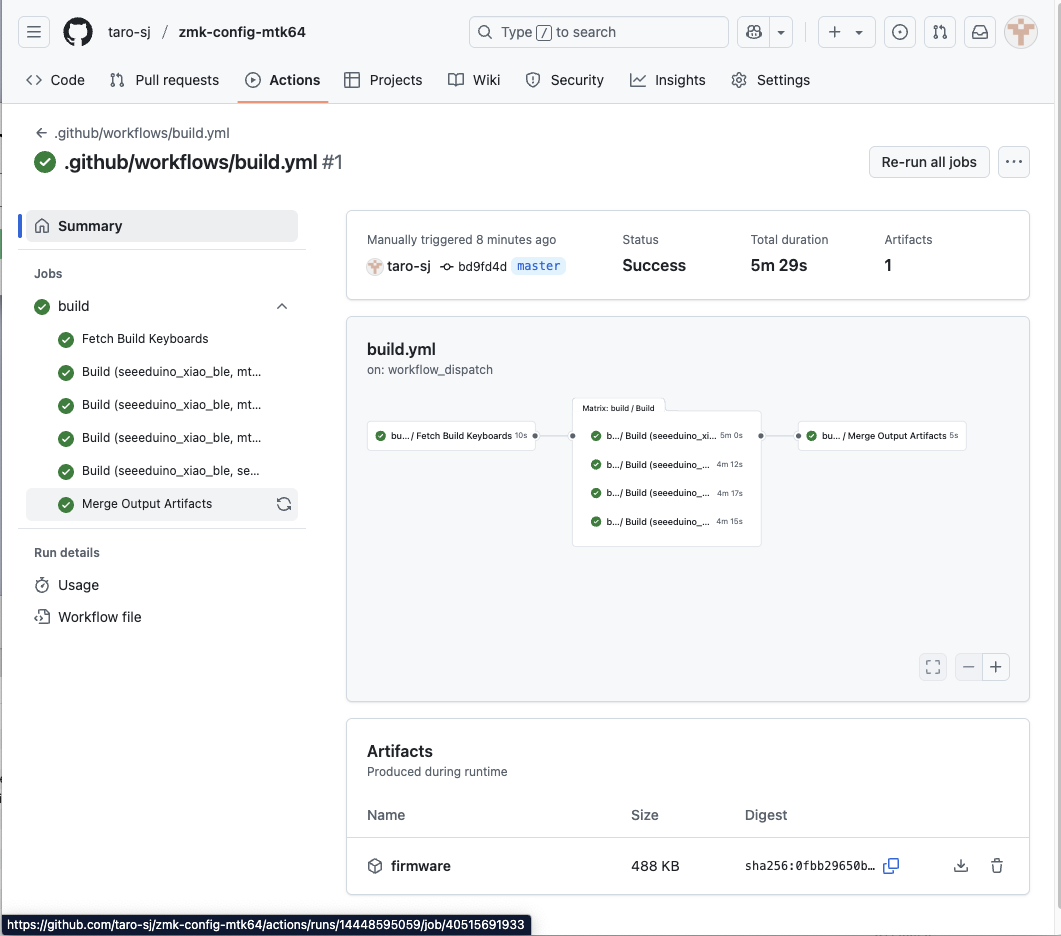
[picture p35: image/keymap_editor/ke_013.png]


14. Artifact download URL:のリンクから、ビルドしたファームウェアをダウンロード
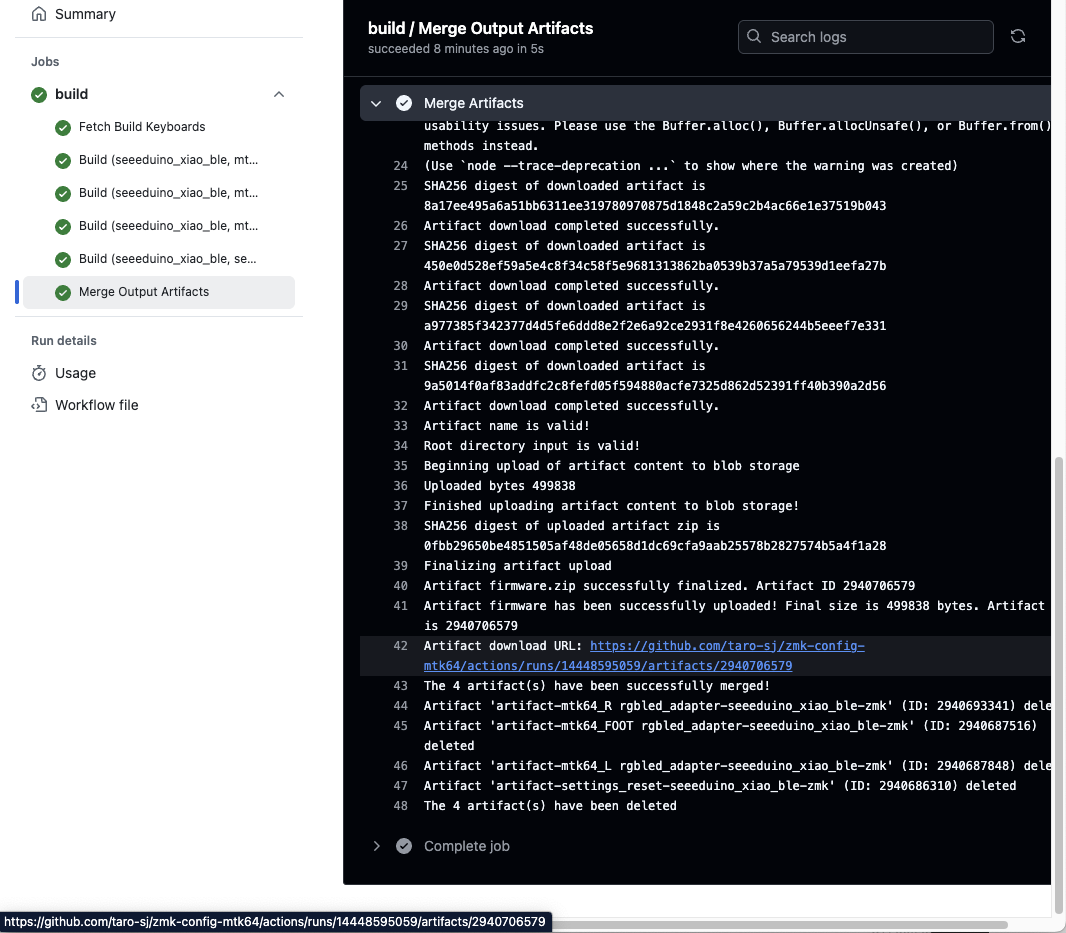
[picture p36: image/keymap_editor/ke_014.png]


15. [ファームウェア書き込み](#ファームウェア書き込み)の手順に従って書き込み

## トラックボール設定

各レイヤーごとの動作について説明します。

* **Layer 0** は通常レイヤーです。これはデフォルトのレイヤーで、通常のキーボード操作が行われます。

* **Layer 1** はマウスレイヤー（精密モード）です。このレイヤーでは、マウスの精密な操作が可能となります。細かい動きが必要な場合に使用します。

* **Layer 2** もマウスレイヤーですが、精密モードではありません。通常のマウス操作が行えます。

* **Layer 3** はスクロールレイヤーです。このレイヤーでは、スクロール操作が可能となります。ウェブページやドキュメントの閲覧時に便利です。

* **Layer 4** と **Layer 5** は未使用のレイヤーです。これらのレイヤーには任意のキーコードを設定することができます。ユーザーの好みに応じてカスタマイズが可能です。

* **Layer 6** は自動マウスレイヤーです。トラックボールの操作が一定距離に達すると、自動的にこのレイヤーに切り替わり、N,Mキーで左右クリック操作が可能になります。
一定時間経過後レイヤーは元のレイヤーに戻ります。

### トラックボール設定変更

トラックボールの設定を変更するには、まずリポジトリをフォークしてソースコードを修正する必要があります。フォークとは、他のユーザーのリポジトリを自分のアカウントにコピーし、自由に変更を加えることができる機能です。

フォークしたソースコードを修正すると、GitHub Actionsにより自動的にビルドが行われます。GitHub Actionsは、リポジトリに変更が加えられた際に自動的にビルドやテストを実行するCI/CDツールです。

ビルドが完了すると、生成されたファームウェアをダウンロードして適用することができます。これにより、トラックボールの設定が反映された新しいファームウェアがキーボードにインストールされ、カスタマイズされた動作を実現することができます。

#### レイヤー設定変更

フォークしたソースの設定を修正する際には、以下のリンク先の設定ファイルを参照してください: [mtk64_R.overlay](https://github.com/mentako-ya/zmk-config-mtk64/blob/master/config/boards/shields/mtk64/mtk64_R.overlay#L58-L67)。

```markdown
    trackball: trackball@0 {
        ~
        ~
        snipe-layers = <1>;
        scroll-layers = <3>;
        automouse-layer = <6>;
    };
```

この設定では、トラックボールの各機能に対応するレイヤーが指定されています。

`snipe-layers`は精密操作用のレイヤー1、

`scroll-layers`はスクロール操作用のレイヤー3、

`automouse-layer`は自動マウス操作用のレイヤー6に設定されています。

もしこれらの機能切り替えを使用しない場合は、不要な設定を削除することができます。これにより、不要な機能が無効化されます。

#### トラックボール設定値調整

フォークしたソースの設定を修正してトラックボールセンサーの感度、自動マウスレイヤーに切り替わるまでの移動距離などを設定可能です。

https://github.com/mentako-ya/zmk-config-mtk64/blob/master/config/boards/shields/mtk64/mtk64_R.conf#L12-L34

```
    CONFIG_PMW3610=y
    CONFIG_PMW3610_CPI=1000
    CONFIG_PMW3610_CPI_DIVIDOR=1
    CONFIG_PMW3610_ORIENTATION_90=y
    CONFIG_PMW3610_SNIPE_CPI=800
    CONFIG_PMW3610_SNIPE_CPI_DIVIDOR=4
    CONFIG_PMW3610_SCROLL_TICK=16
    CONFIG_PMW3610_INVERT_X=y
    CONFIG_PMW3610_INVERT_SCROLL_X=n
    CONFIG_PMW3610_RUN_DOWNSHIFT_TIME_MS=3264
    CONFIG_PMW3610_POLLING_RATE_250=y
    CONFIG_PMW3610_AUTOMOUSE_TIMEOUT_MS=700
    CONFIG_PMW3610_AUTOMOUSE_THRESHOLD=10
    CONFIG_PMW3610_SMART_ALGORITHM=y
```

# ケースデータ

[ケースデータ ダウンロード](casedata/)

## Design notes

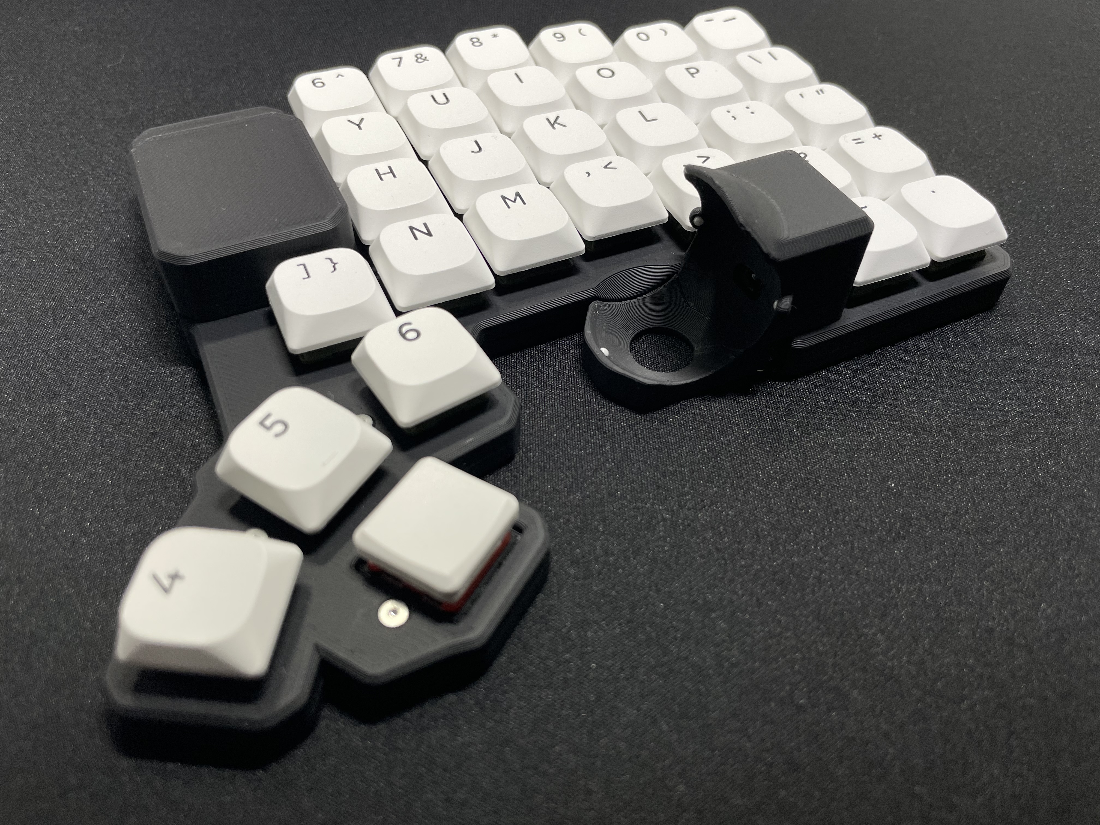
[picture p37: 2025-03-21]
image/mtk64ebt_R2.jpg

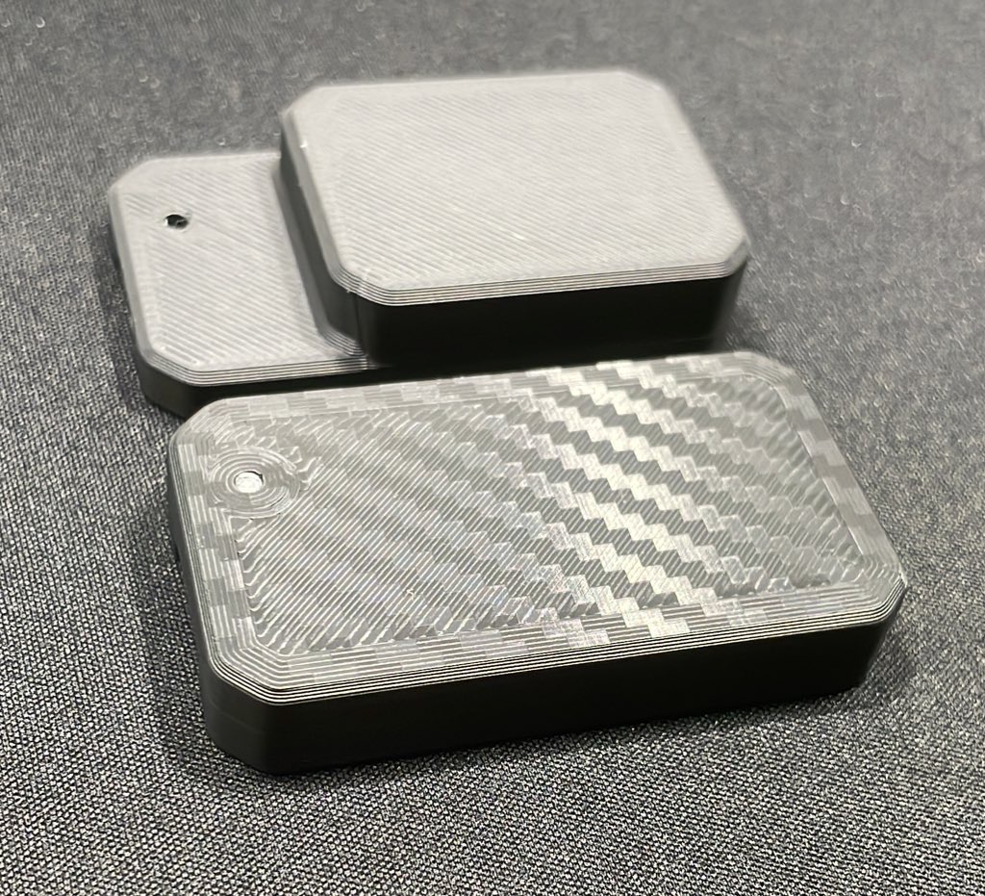
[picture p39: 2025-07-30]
image/rev3/mtk64ebt_rev3_battery_case.JPG

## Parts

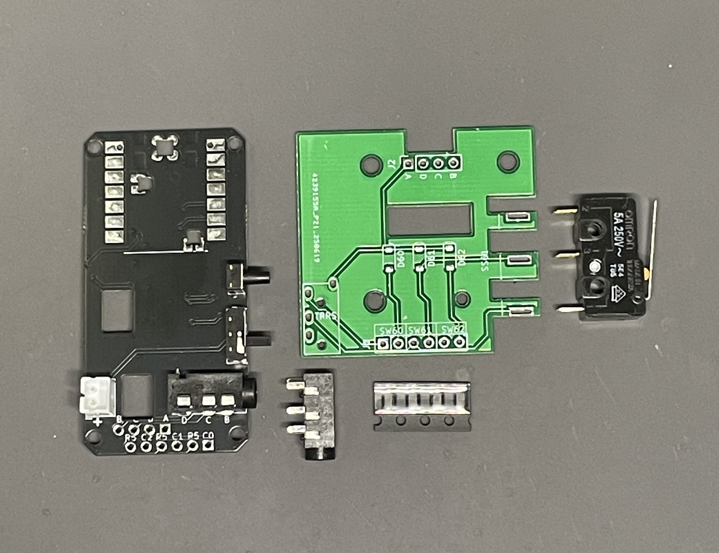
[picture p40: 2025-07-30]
image/rev3/9.fooswitch_btmodule_parts.jpg

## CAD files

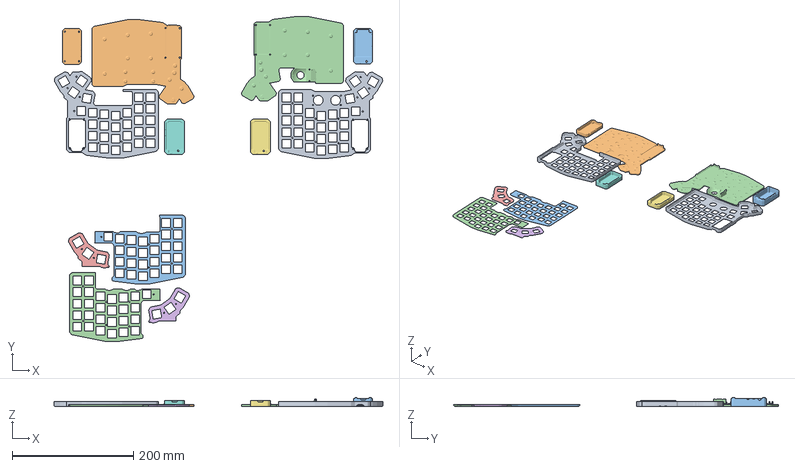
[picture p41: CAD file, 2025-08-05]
casedata/rev3/mtk64ebt_rev3_StanderdParts.3mf
540.9 x 535.1 x 15.4 mm
Body_enc
Body_enc_bottom
top_plate_ball_body_RH
top_plate_enc_body
top_plate_ball_thumb_LH
top_plate_enc_thumb
Body_mcu_LH
Body_mcu_RH
Body_ball_RH
fm_lower
fm_upper
BallCaseLower_RH

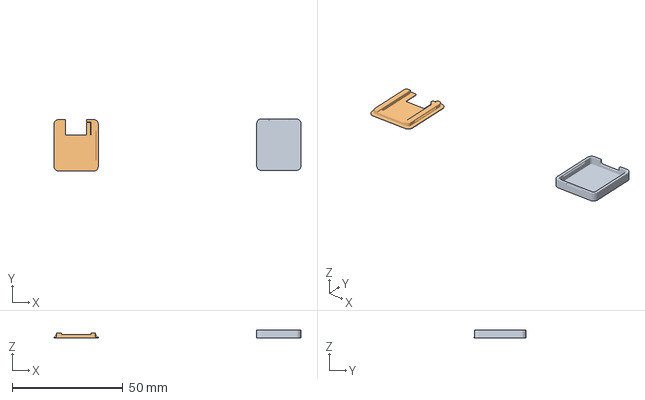
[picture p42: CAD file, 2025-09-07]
casedata/XiaoBle/XiaoBleDongle.3mf
111.5 x 23.5 x 3.50 mm
lower
upper

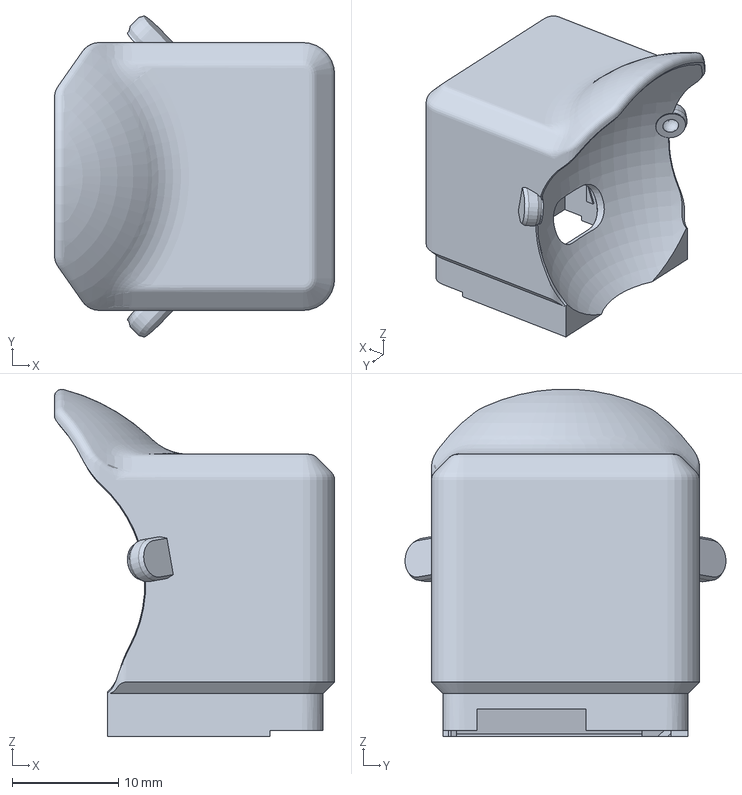
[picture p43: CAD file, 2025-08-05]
casedata/rev3/mtk64ebt_rev3_ballCase_RH.3mf
26.4 x 30.2 x 32.7 mm

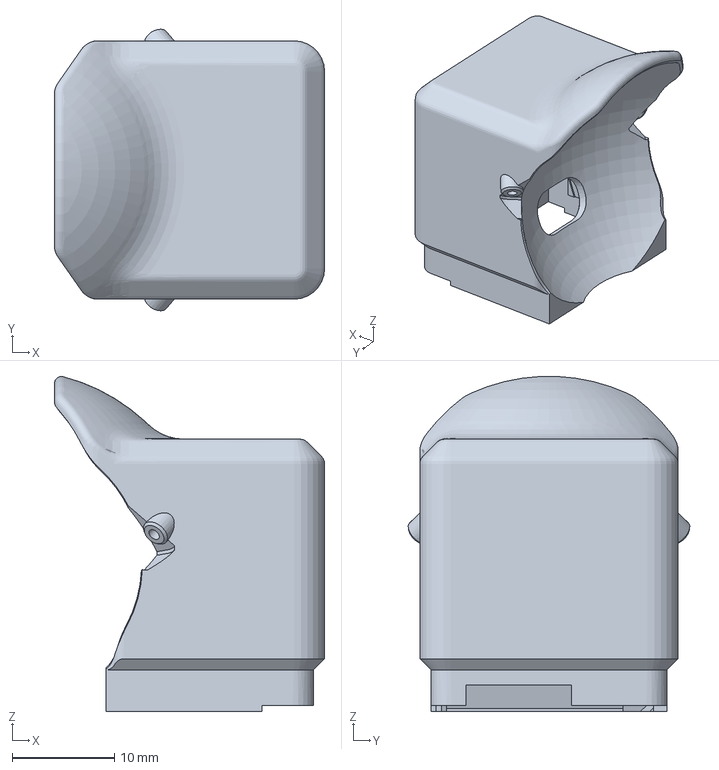
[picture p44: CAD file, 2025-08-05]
casedata/rev3/mtk64ebt_rev3_ballBearingCase_RH.3mf
26.4 x 27.5 x 32.7 mm

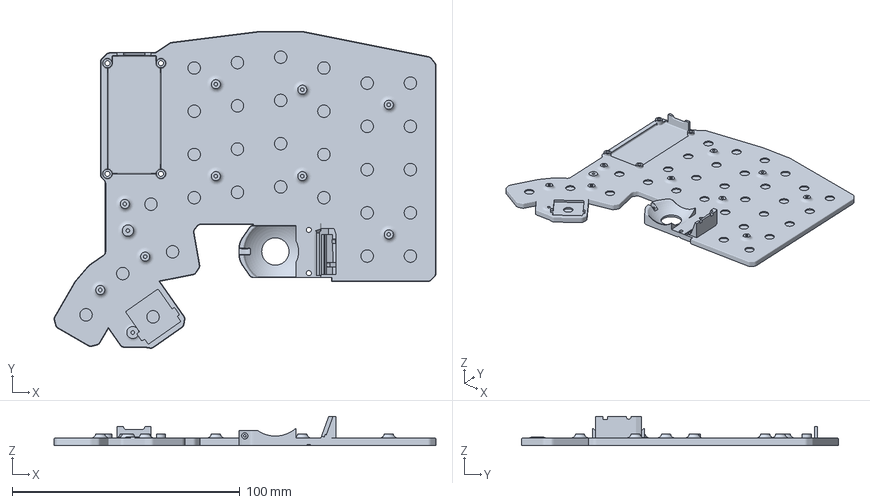
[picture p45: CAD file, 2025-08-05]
casedata/rev3/mtk64ebt_rev3_bodyBallBeringBottmn_RH.3mf
167.9 x 139.2 x 12.9 mm

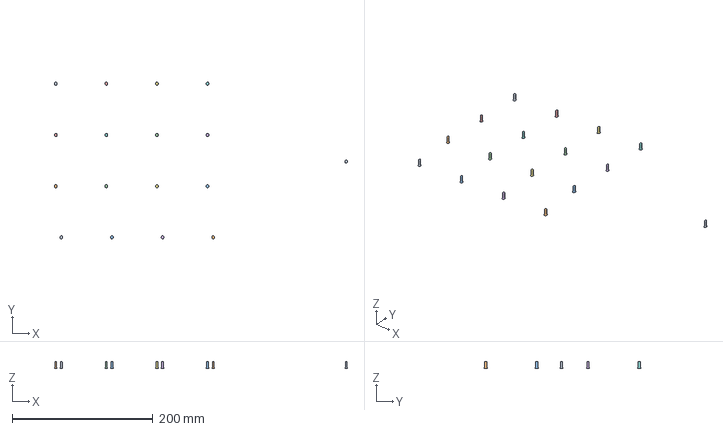
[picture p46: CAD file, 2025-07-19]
casedata/rev3/mtk64ebt_rev3_footmodule_lens.3mf
415.7 x 222.7 x 9.50 mm
fm_lens x 17

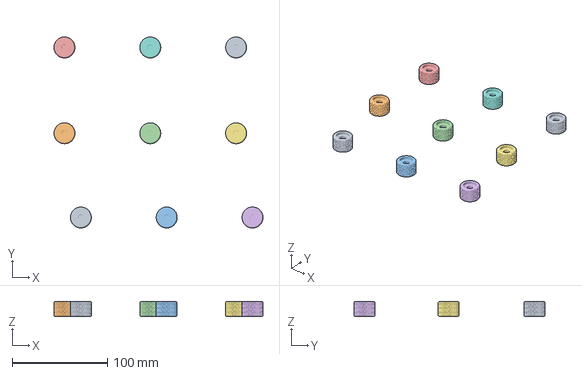
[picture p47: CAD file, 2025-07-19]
casedata/rev3/mtk64ebt_rev3_encoder_knob.3mf
219.2 x 200.3 x 16.0 mm
KanbA x 9

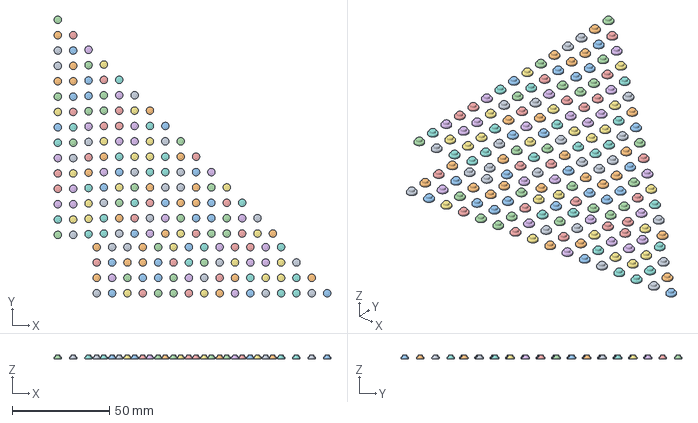
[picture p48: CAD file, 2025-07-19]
casedata/rev3/mtk64ebt_rev3_LED_lens.3mf
142.4 x 144.5 x 2.00 mm
LED_lens x 178

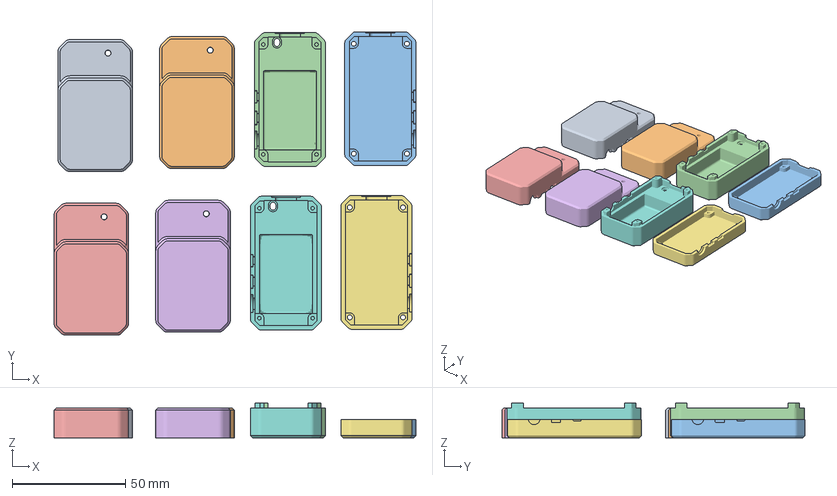
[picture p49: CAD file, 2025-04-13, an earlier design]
casedata/rev1/mtk64ebt_mcu_foot-bambu.3mf
160.0 x 134.1 x 15.4 mm
Body_mcu_LH x 2
Body_mcu_RH x 2
fm_lower x 2
fm_upper x 2

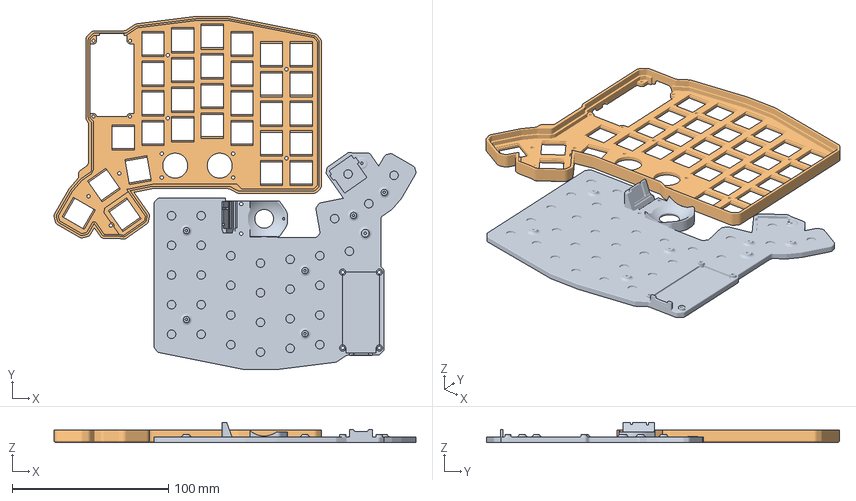
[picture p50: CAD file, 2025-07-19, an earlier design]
casedata/rev2/mtk64ebt_rev2_Body_UL_LR.3mf
231.9 x 226.4 x 12.9 mm
アセンブリ x 2

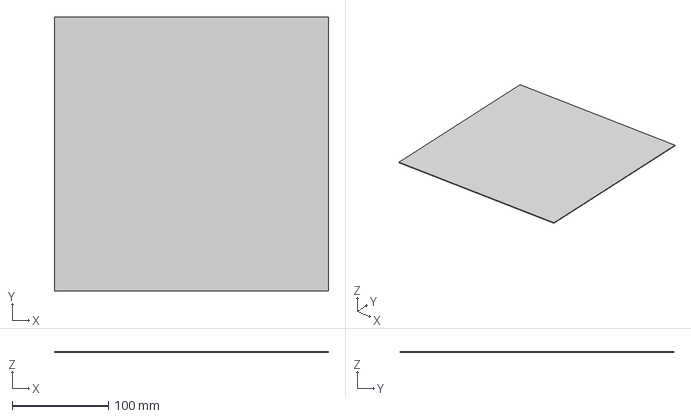
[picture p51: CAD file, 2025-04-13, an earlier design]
casedata/rev1/flatbed_test.3mf
285.0 x 285.0 x 1.00 mm

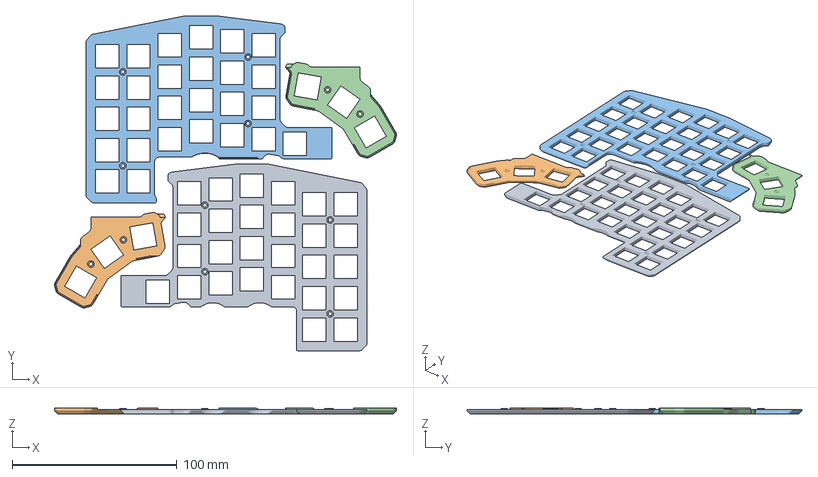
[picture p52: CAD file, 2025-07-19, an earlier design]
casedata/rev2/mtk64ebt_rev2_top_plate_LR.3mf
207.6 x 203.3 x 3.62 mm
top_plate_enc_body
top_plate_enc_thumb
top_plate_ball_body
top_plate_ball_thumb

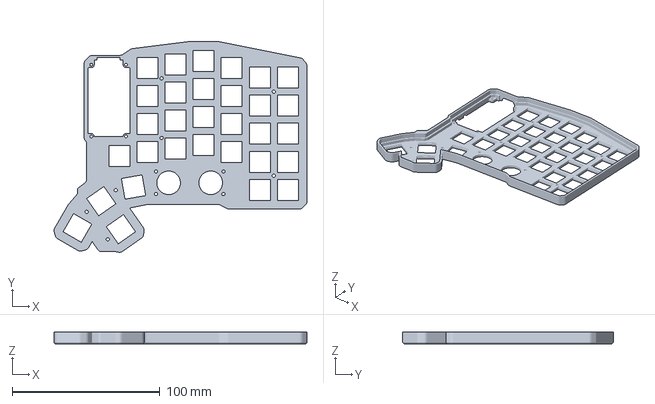
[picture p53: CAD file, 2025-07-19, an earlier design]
casedata/rev2/mtk64ebt_rev2_Body_enc_LH.3mf
171.4 x 142.8 x 8.20 mm

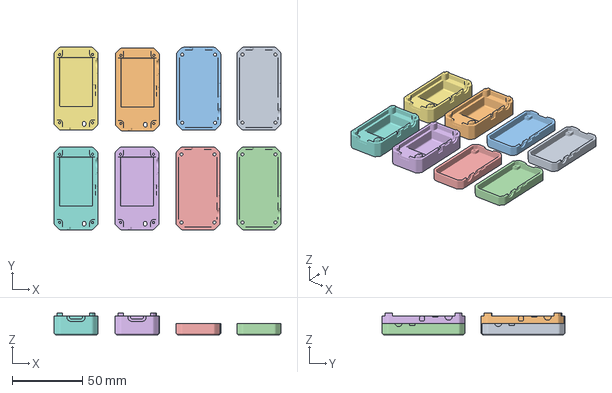
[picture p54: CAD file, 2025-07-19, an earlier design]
casedata/rev2/mtk64ebt_rev2_footmodule_case.3mf
162.0 x 130.4 x 15.4 mm
fm_lower x 4
fm_upper x 4

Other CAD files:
casedata/rev1/mtk64ebt_mcu_foot_encoder.3mf
casedata/rev1/mtk64ebt_EncoderKnob_bambu.3mf
casedata/rev1/mtk64ebt_Body_LU_RL.3mf
casedata/rev2/mtk64ebt_rev2_ballcase_off10_deg10_RH.3mf
casedata/rev1/mtk64ebt_Body_RU_LL.3mf
casedata/rev1/mtk64ebt_Body_ball_LH.3mf
casedata/rev1/mtk64ebt_Body_ball_RH.3mf
casedata/rev1/mtk64ebt_Body_ball_bottom_LH.3mf
casedata/rev1/mtk64ebt_Body_ball_bottom_RH.3mf
casedata/rev1/mtk64ebt_Body_enc_LH.3mf
casedata/rev1/mtk64ebt_Body_enc_bottom_LH.3mf
casedata/rev1/mtk64ebt_EncoderKnob.3mf
casedata/rev1/mtk64ebt_ballCaseUpper_LH.3mf
casedata/rev1/mtk64ebt_ballCaseUpper_RH.3mf
casedata/rev1/mtk64ebt_body_mcu_LR.3mf
casedata/rev1/mtk64ebt_footmodule_case.3mf
casedata/rev1/mtk64ebt_top_plate_LR.3mf
casedata/rev2/Ballcase_off10_deg10.stl
casedata/rev2/Body_mcu_LH.stl
casedata/rev2/Body_mcu_RH.stl
casedata/rev2/KnobA.stl
casedata/rev2/body_encoder.stl
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

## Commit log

2025-03-21 mtk64ebt 初期コミット (+13 squashed commits) Squashed commits: [39a16b9] configure debounce 15ms [39463d0] fix LSHIFT mapping [d32bd76] update casedata cxprj [86f56d0] Add firmware. AUTO_MOUSE_THRESHOLD = 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
    [mtk64ebt_Body_ball_LH.3mf, mtk64ebt_Body_ball_RH.3mf, mtk64ebt_Body_ball_bottom_LH.3mf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]
2025-04-13 3mf更新
    [mtk64ebt_Body_enc_LH.3mf, mtk64ebt_EncoderKnob.3mf, mtk64ebt_ballCaseUpper_LH.3mf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]
2025-04-13 rev2ケースデータ
    [flatbed_test.3mf, mtk64ebt_Body_LU_RL.3mf, mtk64ebt_Body_RU_LL.3mf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]
2025-04-13 ケースデータLR配置修正
    [mtk64ebt_rev2_Body_ball_LH.3mf, mtk64ebt_rev2_Body_ball_RH.3mf, mtk64ebt_rev2_Body_ball_bottom_LH.3mf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]
2025-04-14 キーマップエディターの使用方法をREADMEに追加
2025-04-14 mtk64ebt_rev2_ballcase_RH.3mfのバイナリファイルを更新
    [mtk64ebt_rev2_ballcase_RH.3mf]
2025-04-19 README更新 stlデータ追加
    [Body_mcu_LH.stl, Body_mcu_RH.stl, KnobA.stl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]
2025-04-19 Update README.md
    テキスト修正
2025-04-19 目次修正
2025-04-19 Bluetooth接続先の切り替え方法を更新
2025-04-21 フットスイッチの作成方法画像を追加 接続情報を更新
2025-04-21 casedata/rev2更新
    [footmodule_lower.stl, footmodule_upper.stl, mtk64ebt_rev2_Body_UL_LR.3mf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]
2025-04-23 ファームウェア書き込み手順を明確化
2025-04-25 ファームウェア更新 レイヤー表示機能追加
2025-04-27 Ball case deg10
    [Ballcase_off10_deg10.stl, mtk64ebt_rev2_ballcase_off10_deg10_RH.3mf]
2025-05-04 Add scroll behavior configuration for mouse wheel in mtk64 keymap
2025-05-10 左右構成ファーム更新
2025-07-19 add casedata rev3
    [mtk64ebt_rev2_Body_UL_LR.3mf, mtk64ebt_rev2_Body_UR_LL.3mf, mtk64ebt_rev2_Body_ball_RH.3mf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]
2025-07-27 ベアリングケースデータ追加
    [mtk64ebt_rev3_ballBearingCase_RH.3mf, mtk64ebt_rev3_bodyBallBeringBottmn_RH.3mf]
2025-07-27 ベアリングスペース拡張
    [mtk64ebt_rev3_ballBearingCase_RH.3mf, mtk64ebt_rev3_bodyBallBeringBottmn_RH.3mf]
2025-07-30 ドングル仕様ファームウェア
2025-07-30 rev3対応 dongleモジュールファームウェア
2025-07-30 ベアリング仕様トラックボールについて
2025-07-30 イメージサイズ修正
2025-07-30 ドングル使用イメージ
2025-07-30 XIAO BLE ドングル
2025-08-05 ベアリングケースセンサー位置調整
    [mtk64ebt_rev3_ballBearingCase_RH.3mf, mtk64ebt_rev3_bodyBallBeringBottmn_RH.3mf]
2025-08-05 トラックボールケースセンサー位置調整
    [mtk64ebt_rev3_StanderdParts.3mf, mtk64ebt_rev3_ballCase_RH.3mf]
2025-09-03 Update README.md
    [Copy the master branch only] のチェックボックスについて追記
2025-09-07 ドングルケースデータ
    [XiaoBleDongle.3mf]
